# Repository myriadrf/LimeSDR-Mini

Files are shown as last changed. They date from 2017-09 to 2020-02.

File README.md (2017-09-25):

# LimeSDR-Mini

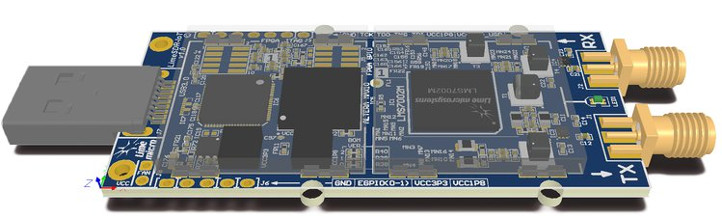
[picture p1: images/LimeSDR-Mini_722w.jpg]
LimeSDR-Mini board


The [LimeSDR-Mini](https://myriadrf.org/projects/limesdr/) board provides a hardware platform for developing and prototyping high-performance and logic-intensive digital and RF designs using Altera’s MAX10 FPGA and Lime Microsystems transceiver.

* **FPGA Features**
  * 169-pin FBGA package
  * 16 K Les
  * 549 KB M9K memory
  * 2,368 KB user flash memory
  * 4 x fractional phase locked loops (PLLs)
  * 45 x 18x18-bit multipliers
  * 130 x general purpose input/output (GPIO)
  * Single supply voltage
  * Flash feature
  * FPGA configuration via JTAG
* **EEPROM memory:** 2 x 128 KB for RF transciever MCU firmware and data
* **Flash memory:** 1 x 4 MB flash memory for data
* **General user inputs/outputs:**
  * 2 x dual color (red + green) LED
  * 8 x FPGA GPIO pinheader (3.3 V)
* **Connectivity:**
  * USB 3.0 Type-A (FTDI FT601 controller)
  * 2 x coaxial RF (SMA) connectors (each can be switched between high and low frequency bands)
  * U.FL connector for external clock source
  * FPGA GPIO headers
  * FPGA JTAG connector
* **Clock system:**
  * 30.72 MHz onboard VCTCXO
  * Possibility to tune VCTCXO with onboard DAC
  * External clock input via U.FL connector
* **Board dimensions:** 69 mm x 31.4 mm

## Contents

The directory structure is as follows:

      hardware/<version>/
          Libraries/             - Component Libraries
          OutputJobs/            - Output jobs
          PCB/                   - PCB design
          Project Outputs/       - BOM, rule check reports, Gerbers, pick & place files, PDFs
          Schematics/            - Schematic diagrams

## Licensing

The hardware designs are licensed under a Creative Commons Attribution 3.0 Unported licence.

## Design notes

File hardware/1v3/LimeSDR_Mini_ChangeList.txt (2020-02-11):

Changes:

LimeSDR_Mini_1v2_DB_DFMr2:
 - R44 made NF (BOM version)
 - LimeSDR_Mini_1v2_schematic_r2.PDF generated
 - LimeSDR_Mini_1v2_BOMr2.xls updated
 
LimeSDR_Mini_1v3:
 - Initial version from LimeSDR_Mini_1v2_DB_DFMr2
 - 1.8V and 3.3V rail LDOs changed
 - Capacitors C194 and C195 added for LMS power
 - HW version changed (affects only PCB physical pin connection)
 - BOM version changed (R44 is now fit)
 - Layout improvements (FT connection)

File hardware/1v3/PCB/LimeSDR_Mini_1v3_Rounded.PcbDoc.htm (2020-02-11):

Reporting Options

# File in Previous Format

Date | : | 2019-05-28
Time | : | 12:08:12
Filename | : | D:\Lime\LimePCBs\LimeSDR_Mini_1v3\Altium Designer design files\PCB\LimeSDR_Mini_1v3_Rounded.PcbDoc

Version | Warning

This file was generated by an earlier version of the software

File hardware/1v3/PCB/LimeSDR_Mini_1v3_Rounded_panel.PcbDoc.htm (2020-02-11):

Reporting Options

# File in Previous Format

Date | : | 2019-05-28
Time | : | 12:52:55
Filename | : | D:\Lime\LimePCBs\LimeSDR_Mini_1v3\Altium Designer design files\PCB\LimeSDR_Mini_1v3_Rounded_panel.PcbDoc

Version | Warning

This file was generated by an earlier version of the software

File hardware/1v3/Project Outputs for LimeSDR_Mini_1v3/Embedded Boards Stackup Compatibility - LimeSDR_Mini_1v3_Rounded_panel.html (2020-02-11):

Altium customize

# Stackup Compatibility

Date: | | 2019-06-04
Time: | | 17:38:27
Elapsed Time: | | 00:00:00
Filename: | | d:\Lime\LimePCBs\LimeSDR_Mini_1v3\Altium Designer design files\PCB\LimeSDR_Mini_1v3_Rounded_panel.PcbDoc

## Layer Stack Compatibility Table

LimeSDR_Mini_1v3_Rounded_panel | LimeSDR_Mini_1v3_Rounded
Top (Signal) | Top (Signal)
L2 (Signal) | L2 (Signal)
L3 (Signal) | L3 (Signal)
L4 (Signal) | L4 (Signal)
L5 (Signal) | L5 (Signal)
L6 (Signal) | L6 (Signal)
L7 (Signal) | L7 (Signal)
Bottom (Signal) | Bottom (Signal)
Open Layer Stack Manager | Open Layer Stack Manager

Back to top

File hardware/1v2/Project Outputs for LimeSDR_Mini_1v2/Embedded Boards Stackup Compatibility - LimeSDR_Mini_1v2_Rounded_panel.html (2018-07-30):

Altium customize

# Stackup Compatibility

Date: | | 2018-04-09
Time: | | 12:49:33
Elapsed Time: | | 00:00:00
Filename: | | E:\Lime Micro\Lime PCBs\LimeSDR_Mini_1v2\Altium Designer design files\PCB\LimeSDR_Mini_1v2_Rounded_panel.PcbDoc

## Layer Stack Compatibility Table

LimeSDR_Mini_1v2_Rounded_panel | LimeSDR_Mini_1v2_Rounded
Top (Signal) | Top (Signal)
L2 (Signal) | L2 (Signal)
L3 (Signal) | L3 (Signal)
L4 (Signal) | L4 (Signal)
L5 (Signal) | L5 (Signal)
L6 (Signal) | L6 (Signal)
L7 (Signal) | L7 (Signal)
Bottom (Signal) | Bottom (Signal)
Open Layer Stack Manager | Open Layer Stack Manager

Back to top

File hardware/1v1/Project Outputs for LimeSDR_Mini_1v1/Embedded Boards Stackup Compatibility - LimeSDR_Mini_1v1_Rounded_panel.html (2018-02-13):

Altium customize

# Stackup Compatibility

Date: | | 2017-11-28
Time: | | 12:33:18
Elapsed Time: | | 00:00:00
Filename: | | E:\Lime Micro\Lime PCBs\LimeSDR_Mini_1v1\Altium Designer design files\PCB\LimeSDR_Mini_1v1_Rounded_panel.PcbDoc

## Layer Stack Compatibility Table

LimeSDR_Mini_1v1_Rounded_panel | LimeSDR_Mini_1v1_Rounded
Top (Signal) | Top (Signal)
L2 (Signal) | L2 (Signal)
L3 (Signal) | L3 (Signal)
L4 (Signal) | L4 (Signal)
L5 (Signal) | L5 (Signal)
L6 (Signal) | L6 (Signal)
L7 (Signal) | L7 (Signal)
Bottom (Signal) | Bottom (Signal)
Open Layer Stack Manager | Open Layer Stack Manager

Back to top

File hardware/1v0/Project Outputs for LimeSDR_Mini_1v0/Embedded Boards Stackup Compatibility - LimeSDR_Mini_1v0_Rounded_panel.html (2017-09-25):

Altium customize

# Stackup Compatibility

Date: | | 2017-09-22
Time: | | 12:15:54
Elapsed Time: | | 00:00:00
Filename: | | D:\Aleksandr\Desktop\LimeSDR_Mini_1v0_Rounded_DFMr1\PCB\LimeSDR_Mini_1v0_Rounded_panel.PcbDoc

## Layer Stack Compatibility Table

LimeSDR_Mini_1v0_Rounded_panel | LimeSDR_Mini_1v0_Rounded
Top (Signal) | Top (Signal)
L2 (Signal) | L2 (Signal)
L3 (Signal) | L3 (Signal)
L4 (Signal) | L4 (Signal)
L5 (Signal) | L5 (Signal)
L6 (Signal) | L6 (Signal)
L7 (Signal) | L7 (Signal)
Bottom (Signal) | Bottom (Signal)
Open Layer Stack Manager | Open Layer Stack Manager

Back to top

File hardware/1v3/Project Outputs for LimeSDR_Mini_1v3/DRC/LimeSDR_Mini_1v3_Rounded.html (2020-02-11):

Altium

# Design Rule Verification Report

Date: | | 2019-06-04
Time: | | 17:38:40
Elapsed Time: | | 00:00:40
Filename: | | d:\Lime\LimePCBs\LimeSDR_Mini_1v3\Altium Designer design files\PCB\LimeSDR_Mini_1v3_Rounded.PcbDoc

Warnings: | | 0
Rule Violations: | | 0

## Summary

Warnings | Count
Total | 0

Rule Violations | Count
Clearance Constraint (Gap=0.1mm) (All),(All) | 0
Short-Circuit Constraint (Allowed=No) (All),(All) | 0
Un-Routed Net Constraint ( (All) ) | 0
Modified Polygon (Allow modified: No), (Allow shelved: No) | 0
Width Constraint (Min=0.1mm) (Max=5mm) (Preferred=0.2mm) (All) | 0
Width Constraint (Min=0.1mm) (Max=7mm) (Preferred=0.2mm) (All) | 0
Routing Layers(All) | 0
Routing Via (MinHoleWidth=0.2mm) (MaxHoleWidth=4.5mm) (PreferredHoleWidth=0.2mm) (MinWidth=0.31mm) (MaxWidth=5mm) (PreferedWidth=0.4mm) (All) | 0
Differential Pairs Uncoupled Length using the Gap Constraints (Min=0.1mm) (Max=0.2mm) (Prefered=0.1mm) and Width Constraints (Min=0.1mm) (Max=0.4mm) (Prefered=0.1mm) (InNet('FX3_XTAL_N') or InNet('FX3_XTAL_P')) | 0
Differential Pairs Uncoupled Length using the Gap Constraints (Min=0.1mm) (Max=0.3mm) (Prefered=0.14mm) and Width Constraints (Min=0.2mm) (Max=0.2mm) (Prefered=0.2mm) (InNetClass('FX3_DATA')) | 0
Differential Pairs Uncoupled Length using the Gap Constraints (Min=0.14mm) (Max=0.14mm) (Prefered=0.14mm) and Width Constraints (Min=0.1mm) (Max=0.2mm) (Prefered=0.2mm) (InNetClass('TX_RF')) | 0
Differential Pairs Uncoupled Length using the Gap Constraints (Min=0.1mm) (Max=0.3mm) (Prefered=0.1mm) and Width Constraints (Min=0.1mm) (Max=0.5mm) (Prefered=0.2mm) (All) | 0
Differential Pairs Uncoupled Length using the Gap Constraints (Min=0.1mm) (Max=0.3mm) (Prefered=0.14mm) and Width Constraints (Min=0.1mm) (Max=0.3mm) (Prefered=0.2mm) (InNetClass('RX_RF')) | 0
Power Plane Connect Rule(Relief Connect )(Expansion=0.508mm) (Conductor Width=0.254mm) (Air Gap=0.254mm) (Entries=4) (All) | 0
Hole Size Constraint (Min=0.2mm) (Max=10mm) (All) | 0
Pads and Vias to follow the Drill pairs settings | 0
Hole To Hole Clearance (Gap=0.15mm) (All),(All) | 0
Minimum Solder Mask Sliver (Gap=0.05mm) (All),(All) | 0
Net Antennae (Tolerance=0mm) (All) | 0
Matched Lengths(Tolerance=5mm) (InNetClass('FT_FIFO')) | 0
Matched Lengths(Tolerance=7mm) (InNetClass('LMS_PORT1')) | 0
Matched Lengths(Tolerance=7.5mm) (InNetClass('LMS_PORT2')) | 0
Component Clearance Constraint ( Horizontal Gap = -1mm, Vertical Gap = Infinite ) (InComponent('IC11') or InComponent('IC11A')),(InComponent('IC11') or InComponent('IC11A')) | 0
Component Clearance Constraint ( Horizontal Gap = 0.01mm, Vertical Gap = 0.254mm ) (All),(All) | 0
Component Clearance Constraint ( Horizontal Gap = -1mm, Vertical Gap = Infinite ) (InComponent('R59') or InComponent('R62')),(InComponent('R59') or InComponent('R62')) | 0
Component Clearance Constraint ( Horizontal Gap = -1mm, Vertical Gap = Infinite ) (InComponent('R28') or InComponent('C22') or InComponent('R29') or InComponent('C20')),(InComponent('R28') or InComponent('C22') or InComponent('R29') or InComponent('C20')) | 0
Component Clearance Constraint ( Horizontal Gap = -1mm, Vertical Gap = Infinite ) (InComponent('MECH5') or InComponent('MECH7') or InComponent('MECH15')),(All) | 0
Height Constraint (Min=0mm) (Max=25.4mm) (Prefered=12.7mm) (All) | 0
Total | 0

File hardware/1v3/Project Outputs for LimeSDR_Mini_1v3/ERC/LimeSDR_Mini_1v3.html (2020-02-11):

Altium

# Electrical Rule Check Report

Date: | | 2019-06-04
Time: | | 17:39:24
Filename: | | d:\Lime\LimePCBs\LimeSDR_Mini_1v3\Altium Designer design files\Project Outputs for LimeSDR_Mini_1v3\ERC\LimeSDR_Mini_1v3.html

Class | Document | Message
Warning | 09_Misc.SchDoc | GND contains IO Pin and Power Pin objects (Pin IC10-4,Pin IC2-4,Pin IC9-5,Pin IC5-F4,Pin IC5-G4,Pin IC10-PAD,Pin IC2-PAD)
Warning | 09_Misc.SchDoc | Net DLY_VCC1P8 has no driving source (Pin C193-2,Pin IC12-1,Pin R84-1,Pin R94-2)
Warning | 09_Misc.SchDoc | Net NetC151_2 has no driving source (Pin C151-2,Pin XO1-7)
Warning | 06_LMS7002M_Power.SchDoc | Net NetC173_2 has no driving source (Pin C173-2,Pin FR34-2,Pin IC15-1,Pin IC15-6)
Warning | 06_LMS7002M_Power.SchDoc | Net NetC187_2 has no driving source (Pin C187-2,Pin FR35-2,Pin IC16-1,Pin IC16-6)
Warning | 09_Misc.SchDoc | Net NetC191_1 has no driving source (Pin C191-1,Pin IC12-2,Pin R76-1,Pin R82-2)
Warning | 09_Misc.SchDoc | Net NetC192_1 has no driving source (Pin C192-1,Pin IC13-2,Pin R78-1,Pin R83-2)
Warning | 07_FPGA.SchDoc | Net NetIC5_E7 has no driving source (Pin IC5-E7,Pin R47-2)
Warning | 09_Misc.SchDoc | Net NetIC14_5 has no driving source (Pin IC14-5,Pin R80-1,Pin R81-1)
Warning | 06_LMS7002M_Power.SchDoc | Net NetIC15_5 has no driving source (Pin IC15-5,Pin R86-1,Pin R87-2)
Warning | 06_LMS7002M_Power.SchDoc | Net NetIC16_5 has no driving source (Pin IC16-5,Pin R88-1,Pin R89-2)
Warning | 09_Misc.SchDoc | Net TCXO_VC has no driving source (Pin C161-2,Pin R67-1,Pin R68-1,Pin XO1-1)
Warning | 08_USB3_0_device.SchDoc | Net USB_SSRX_N has no driving source (Pin ESD3-7,Pin IC6-34,Pin J7-8)
Warning | 08_USB3_0_device.SchDoc | Net USB_SSRX_P has no driving source (Pin ESD3-8,Pin IC6-35,Pin J7-9)
Warning | 09_Misc.SchDoc | Net VCC5P0_USB has no driving source (Pin C176-2,Pin C181-2,Pin FR12-2,Pin IC12-7,Pin IC13-1,Pin IC13-7,Pin J3-7,Pin R15-1,Pin R21-1,Pin R41-1,Pin R69-1,Pin R94-1)

Back to top

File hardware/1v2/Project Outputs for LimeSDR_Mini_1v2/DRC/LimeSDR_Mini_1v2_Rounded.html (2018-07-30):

Altium

# Design Rule Verification Report

Date: | | 2018-04-09
Time: | | 12:51:00
Elapsed Time: | | 00:00:55
Filename: | | E:\Saniok\Lime Micro\Lime PCBs\LimeSDR_Mini_1v2\Altium Designer design files\PCB\LimeSDR_Mini_1v2_Rounded.PcbDoc

Warnings: | | 0
Rule Violations: | | 0

## Summary

Warnings | Count
Total | 0

Rule Violations | Count
Component Clearance Constraint ( Horizontal Gap = -1mm, Vertical Gap = Infinite ) (InComponent('IC11') or InComponent('IC11A')),(InComponent('IC11') or InComponent('IC11A')) | 0
Component Clearance Constraint ( Horizontal Gap = -1mm, Vertical Gap = Infinite ) (InComponent('R59') or InComponent('R62')),(InComponent('R59') or InComponent('R62')) | 0
Component Clearance Constraint ( Horizontal Gap = -1mm, Vertical Gap = Infinite ) (InComponent('MECH5') or InComponent('MECH7') or InComponent('MECH15')),(All) | 0
Component Clearance Constraint ( Horizontal Gap = -1mm, Vertical Gap = Infinite ) (InComponent('R28') or InComponent('C22') or InComponent('R29') or InComponent('C20')),(InComponent('R28') or InComponent('C22') or InComponent('R29') or InComponent('C20')) | 0
Differential Pairs Uncoupled Length using the Gap Constraints (Min=0.1mm) (Max=0.2mm) (Prefered=0.1mm) and Width Constraints (Min=0.1mm) (Max=0.4mm) (Prefered=0.1mm) (InNet('FX3_XTAL_N') or InNet('FX3_XTAL_P')) | 0
Matched Lengths(Tolerance=5mm) (InNetClass('FT_FIFO')) | 0
Net Antennae (Tolerance=0mm) (All) | 0
Minimum Solder Mask Sliver (Gap=0.05mm) (All),(All) | 0
Hole To Hole Clearance (Gap=0.15mm) (All),(All) | 0
Routing Layers(All) | 0
Clearance Constraint (Gap=0.1mm) (All),(All) | 0
Short-Circuit Constraint (Allowed=No) (All),(All) | 0
Un-Routed Net Constraint ( (All) ) | 0
Width Constraint (Min=0.1mm) (Max=5mm) (Preferred=0.2mm) (All) | 0
Routing Via (MinHoleWidth=0.2mm) (MaxHoleWidth=4.5mm) (PreferredHoleWidth=0.2mm) (MinWidth=0.31mm) (MaxWidth=5mm) (PreferedWidth=0.4mm) (All) | 0
Pads and Vias to follow the Drill pairs settings | 0
Hole Size Constraint (Min=0.2mm) (Max=10mm) (All) | 0
Differential Pairs Uncoupled Length using the Gap Constraints (Min=0.1mm) (Max=0.3mm) (Prefered=0.1mm) and Width Constraints (Min=0.1mm) (Max=0.5mm) (Prefered=0.2mm) (All) | 0
Component Clearance Constraint ( Horizontal Gap = 0.01mm, Vertical Gap = 0.254mm ) (All),(All) | 0
Modified Polygon (Allow modified: No), (Allow shelved: No) | 0
Matched Lengths(Tolerance=7mm) (InNetClass('LMS_PORT1')) | 0
Matched Lengths(Tolerance=7.5mm) (InNetClass('LMS_PORT2')) | 0
Differential Pairs Uncoupled Length using the Gap Constraints (Min=0.1mm) (Max=0.3mm) (Prefered=0.14mm) and Width Constraints (Min=0.2mm) (Max=0.2mm) (Prefered=0.2mm) (InNetClass('FX3_DATA')) | 0
Differential Pairs Uncoupled Length using the Gap Constraints (Min=0.14mm) (Max=0.14mm) (Prefered=0.14mm) and Width Constraints (Min=0.1mm) (Max=0.2mm) (Prefered=0.2mm) (InNetClass('TX_RF')) | 0
Differential Pairs Uncoupled Length using the Gap Constraints (Min=0.1mm) (Max=0.3mm) (Prefered=0.14mm) and Width Constraints (Min=0.1mm) (Max=0.3mm) (Prefered=0.2mm) (InNetClass('RX_RF')) | 0
Width Constraint (Min=0.1mm) (Max=7mm) (Preferred=0.2mm) (All) | 0
Power Plane Connect Rule(Relief Connect )(Expansion=0.508mm) (Conductor Width=0.254mm) (Air Gap=0.254mm) (Entries=4) (All) | 0
Height Constraint (Min=0mm) (Max=25.4mm) (Prefered=12.7mm) (All) | 0
Total | 0

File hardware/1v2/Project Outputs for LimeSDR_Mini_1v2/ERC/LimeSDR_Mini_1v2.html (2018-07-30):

Altium

# Electrical Rule Check Report

Date: | | 2018-04-09
Time: | | 12:51:56
Filename: | | E:\Saniok\Lime Micro\Lime PCBs\LimeSDR_Mini_1v2\Altium Designer design files\Project Outputs for LimeSDR_Mini_1v2\ERC\LimeSDR_Mini_1v2.html

Class | Document | Message
Warning | 09_Misc.SchDoc | GND contains IO Pin and Power Pin objects (Pin IC10-4,Pin IC2-4,Pin IC9-5,Pin IC5-E3,Pin IC5-E4,Pin IC5-F4,Pin IC5-G4,Pin IC10-PAD,Pin IC2-PAD)
Warning | 09_Misc.SchDoc | Net NetC151_2 has no driving source (Pin C151-2,Pin XO1-7)
Warning | 06_LMS7002M_Power.SchDoc | Net NetC173_2 has no driving source (Pin C173-2,Pin FR34-2,Pin IC15-1,Pin IC15-6)
Warning | 06_LMS7002M_Power.SchDoc | Net NetC187_2 has no driving source (Pin C187-2,Pin FR35-2,Pin IC16-1,Pin IC16-6)
Warning | 07_FPGA.SchDoc | Net NetIC5_E7 has no driving source (Pin IC5-E7,Pin R47-2)
Warning | 09_Misc.SchDoc | Net NetIC14_5 has no driving source (Pin IC14-5,Pin R80-1,Pin R81-1)
Warning | 06_LMS7002M_Power.SchDoc | Net NetIC15_5 has no driving source (Pin IC15-5,Pin R86-1,Pin R87-2)
Warning | 06_LMS7002M_Power.SchDoc | Net NetIC16_5 has no driving source (Pin IC16-5,Pin R88-1,Pin R89-2)
Warning | 09_Misc.SchDoc | Net TCXO_VC has no driving source (Pin C161-2,Pin R67-1,Pin R68-1,Pin XO1-1)
Warning | 08_USB3_0_device.SchDoc | Net USB_SSRX_N has no driving source (Pin ESD3-7,Pin IC6-34,Pin J7-8)
Warning | 08_USB3_0_device.SchDoc | Net USB_SSRX_P has no driving source (Pin ESD3-8,Pin IC6-35,Pin J7-9)

Back to top

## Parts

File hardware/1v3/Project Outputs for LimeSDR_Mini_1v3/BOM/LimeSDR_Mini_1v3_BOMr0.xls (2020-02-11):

Item # | Comment | Quantity | Designator | Footprint | Manufacturer | Manufacturer Part Number 1 | Supplier 1 | Supplier Part Number 1 | Part Description | Assembly Info
1 | 10pF, 25V | 1 | C1 | CAP0402 | AVX | 04023A100JAT2A | Farnell | 2332478RL | 10pF ±5% 25V C0G, NP0 Ceramic Capacitor -55°C ~ 125°C Surface Mount, MLCC 0402 (1005 Metric) 0.039" L x 0.020" W (1.00mm x 0.50mm)
2 | 1uF, 10V | 6 | C2, C153, C157, C164, C168, C193 | CAP0402 | TDK | C1005X5R1E105K050BC | Digi-Key | 445-9066-1-ND | 1µF ±10% 10V X5R Ceramic Capacitor -55°C ~ 85°C Surface Mount, MLCC 0402 (1005 Metric) 0.039" L x 0.020" W (1.00mm x 0.50mm)
3 | 100pF, 50V | 18 | C3, C5, C7, C8, C12, C19, C20, C22, C23, C159, C160, C166, C167, C170, C171, C183, C186, C189 | CAP0402 | Yageo | CC0402JRNPO9BN101 | Digi-Key | 311-1024-1-ND | 100pF ±5% 50V C0G, NP0 Ceramic Capacitor -55°C ~ 125°C Surface Mount, MLCC 0402 (1005 Metric) 0.039" L x 0.020" W (1.00mm x 0.50mm) | NF(C12 C19 C20 C22 C183 C186 C189)
4 | 100nF, 16V | 26 | C4, C6, C9, C10, C11, C21, C87, C123, C125, C127, C147, C148, C149, C150, C155, C156, C158, C161, C162, C163, C165, C169, C172, C174, MN11, MN14 | CAP0402 | Murata Electronics | GRM155R71C104KA88D | Mouser | 81-GRM155R71C104KA88 | 0.10µF ±10% 16V X7R Ceramic Capacitor -55°C ~ 125°C Surface Mount, MLCC 0402 (1005 Metric) 0.039" L x 0.020" W (1.00mm x 0.50mm) | NF(C11 C21 C150)
5 | 47pF, 50V | 4 | C13, C16, C24, C27 | CAP0402 | TDK Corporation | GRM1555C1H470FA01D | Digi-Key | 490-6241-1-ND | 47pF ±1% 50V C0G, NP0 Ceramic Capacitor -55°C ~ 125°C Surface Mount, MLCC 0402 (1005 Metric) 0.039" L x 0.020" W (1.00mm x 0.50mm)
6 | 510pF | 6 | C14, C15, C25, C26, MN19, MN22 | CAP0402 | Murata Electronics North America | GRM1555C1H511JA01D | Digi-Key | 490-3237-1-ND | 510pF ±5% 50V C0G, NP0 Ceramic Capacitor -55°C ~ 125°C Surface Mount, MLCC 0402 (1005 Metric) 0.039" L x 0.020" W (1.00mm x 0.50mm)
7 | 1uF, 6.3V | 60 | C30, C32, C34, C36, C38, C40, C41, C42, C43, C44, C45, C46, C47, C48, C49, C50, C51, C52, C53, C55, C56, C57, C58, C59, C60, C62, C64, C66, C67, C68, C69, C70, C71, C72, C73, C74, C75, C76, C77, C78, C79, C80, C81, C82, C83, C84, C85, C86, C89, C96, C103, C109, C113, C129, C131, C133, C135, C138, C146, C190 | CAP0201 | TDK Corporation | JMK063ABJ105MP-F | Digi-Key | 587-5864-2-ND | 1µF ±20% 6.3V X5R Ceramic Capacitor -55°C ~ 85°C Surface Mount, MLCC 0201 (0603 Metric) 0.024" L x 0.012" W (0.60mm x 0.30mm)
8 | 1nF, 10% | 11 | C31, C33, C35, C37, C39, C54, C61, C63, C65, C194, C195 | CAP0201 | TDK Corporation | C0603X7R1E102K030BA | Digi-Key | 445-7275-1-ND | 1000pF ±10% 25V X7R Ceramic Capacitor -55°C ~ 125°C Surface Mount, MLCC 0201 (0603 Metric) 0.024" L x 0.012" W (0.60mm x 0.30mm)
9 | 10uF, 6.3V | 11 | C88, C95, C102, C108, C112, C128, C137, C145, C175, C180, C184 | CAP0603 | Yageo | CC0603MRX5R5BB106 | Digi-Key | 311-1448-2-ND | 10µF ±20% 6.3V X5R Ceramic Capacitor -55°C ~ 85°C Surface Mount, MLCC 0603 (1608 Metric) 0.063" L x 0.031" W (1.60mm x 0.80mm)
10 | 100nF, 6.3V | 32 | C90, C91, C92, C93, C94, C97, C98, C99, C100, C101, C104, C105, C106, C107, C110, C111, C114, C115, C116, C117, C118, C119, C120, C121, C122, C130, C132, C134, C136, C139, C141, C143 | CAP0201 | Murata | GRT033C81A104KE01D | Digi-Key | 490-12232-1-ND | 0.10µF ±10% 6.3V X6S Ceramic Capacitor -55°C ~ 105°C Surface Mount, MLCC 0201 (0603 Metric) 0.024" L x 0.012" W (0.60mm x 0.30mm)
11 | 10pF, 5% | 2 | C124, C126 | CAP0402 | AVX | 04023A100JAT2A | Farnell | 2332478RL | 10pF ±5% 25V C0G, NP0 Ceramic Capacitor -55°C ~ 125°C Surface Mount, MLCC 0402 (1005 Metric) 0.039" L x 0.020" W (1.00mm x 0.50mm)
12 | 10nF, 50V | 7 | C17, C18, C28, C29, C140, C142, C144 | CAP0402 | Murata Electronics North America | GRM155R71H103KA88D | Digi-Key | 490-4516-2-ND | 10000pF ±10% 50V Ceramic Capacitor X7R 0402 (1005 Metric)
13 | 18nF, 16V | 1 | C151 | CAP0402 | Yageo | CC0402KRX7R7BB183 | Digi-Key | 311-1706-1-ND | CAP CER 0.018UF 16V X7R 0402
14 | 47pF | 2 | C152, C154 | CAP0402 | TDK Corporation | GRM1555C1H470FA01D | Digi-Key | 490-6241-1-ND | 47pF ±1% 50V C0G, NP0 Ceramic Capacitor -55°C ~ 125°C Surface Mount, MLCC 0402 (1005 Metric) 0.039" L x 0.020" W (1.00mm x 0.50mm) | NF(C152 C154)
15 | 4.7uF, 6.3V | 6 | C173, C178, C179, C185, C187, C188 | CAP0402 | Murata Electronics North America | GRM155R60J475ME87D | Digi-Key | 490-5408-1-ND | 4.7µF ±20% 6.3V X5R Ceramic Capacitor -55°C ~ 85°C Surface Mount, MLCC 0402 (1005 Metric) 0.039" L x 0.020" W (1.00mm x 0.50mm)
16 | 22uF, 10V | 4 | C176, C177, C181, C182 | CAP0603 | TDK Corporation | C1608X5R1A226M080AC | Mouser | 810-C1608X5R1A226M | 22µF ±20% 10V X5R Ceramic Capacitor -55°C ~ 85°C Surface Mount, MLCC 0603 (1608 Metric) 0.063" L x 0.031" W (1.60mm x 0.80mm)
17 | 470pF, 50V | 2 | C191, C192 | CAP0402 | TDK Corporation | C1005C0G1H471J050BA | Digi-Key | 445-2656-6-ND | 470pF ±5% 50V Ceramic Capacitor C0G, NP0 0402 (1005 Metric)
18 | ESD8472 | 2 | ESD1, ESD2 | ESD8472_X3DFN2 | ON Semiconductor | ESD8472MUT5G | Digi-Key | ESD8472MUT5GOSCT-ND | TVS DIODE 5.3VWM 14VC X3DFN2 | NF(ESD1 ESD2)
19 | ESD7016 | 1 | ESD3 | ESD7016 | ON Semiconductor | ESD7016MUTAG | Digi-Key | ESD7016MUTAGOSDKR-ND | TVS DIODE 5VWM 10VC 8UDFN
20 | 5V DC FAN | 1 | FAN1 |  | Sunon Fans | MC30060V2-000U-A99 | Digi-Key | 259-1572-ND | FAN AXIAL 30X6.9MM 5VDC WIRE | NF(FAN1)
21 | Fiducial | 1 | FL1 | Fiducial_local
22 | 600R, 0.27A | 36 | FR1, FR2, FR3, FR4, FR5, FR6, FR7, FR8, FR9, FR10, FR15, FR16, FR17, FR18, FR19, FR23, FR24, FR25, FR26, FR27, FR28, FR29, FR30, FR31, FR32, FR33, FR36, FR37, FR38, FR39, FR40, FR41, FR42, FR43, FR44, FR45 | RES0201 | Taiyo Yuden | BK0603TS601-T | Digi-Key | 587-3277-1-ND | FERRITE BEAD 600 OHM 0201 1LN
23 | 220R, 0.9A | 7 | FR11, FR13, FR14, FR21, FR22, FR34, FR35 | RES0402 | TDK Corporation | MPZ1005S221ET000 | Digi-Key | 445-9329-2-ND | FERRITE BEAD 220 OHM 0402 1LN
24 | 600R, 2A | 2 | FR12, FR20 | RES0805 | TDK Corporation | MPZ2012S601AT000 | Digi-Key | 445-2206-2-ND | FERRITE BEAD 600 OHM 0805 1LN
25 | LMS7002M | 1 | IC1 | LMS7002M_v5 | Lime Microsystems | LMS7002M | Lime Microsystems | LMS7002M | IC FPRF Transceiver LMS7002M; 261 pin aQFN
26 | M24128 | 2 | IC2, IC10 | M24128-DFMC6TG | STMicroelectronics | M24128-DFMC6TG | Digi-Key | 497-15739-1-ND | EEPROM Memory IC 128Kb (16K x 8) I²C 1MHz 450ns 8-UFDFPN (2x3)
27 | SKY13411-374LF | 2 | IC3, IC4 | SKY13411-374LF | Skyworks Solutions Inc. | SKY13411-374LF | Digi-Key | 863-1455-1-ND | RF Switch IC 802.11a/b/g/n DPDT 50 Ohm 6-MLPD (1.5x1.5)
28 | 10M16SAU169C8G | 1 | IC5 | 10M16SAU169C8G | Altera | 10M16SAU169C8G | Digi-Key | 544-3110-ND | IC FPGA/CPLD NV 130 I/O 169UBGA
29 | FT601Q | 1 | IC6 | FT601Q | FTDI, Future Technology Devices International Ltd | FT601Q-B-T | Digi-Key | 768-1311-ND | IC USB3-32BIT SYNC FIFO 76QFN
30 | LMK00105 | 1 | IC7 | LMK00105SQ | Texas Instruments | LMK00105SQ/NOPB | Digi-Key | LMK00105SQ/NOPBCT-ND | IC CLK BUFFER 2:5 200MHZ 24WQFN
31 | LM75 | 1 | IC8 | HWSON8_LM75 | NXP Semiconductors | LM75BTP,147 | Digi-Key | 568-9815-2-ND | SENSOR TEMPERATURE I2C 8HWSON | NF(IC8)
32 | DAC5311IDCKR | 1 | IC9 | AD5601_SOT23-6 | Texas Instruments | DAC5311IDCKR | Digi-Key | 296-24180-1-ND | 8 Bit Digital to Analog Converter 1 SC-70-6
33 | W25Q40EWUXIE | 1 | IC11 | W25Q40EWUXIE_8-USON | Winbond Electronics | W25Q40EWUXIE TR | Digi-Key | W25Q40EWUXIE CT-ND | FLASH - NOR Memory IC 4Mb (512K x 8) SPI 8-USON (2x3)
34 | MX25U1635EM1I | 1 | IC11A | MX25U1635EM1I-10G_SOP8_150mil | Macronix | MX25U1635EM1I-10G | Digi-Key | 1092-1123-ND | FLASH - NOR Memory IC 16Mb (2M x 8) SPI 104MHz 8-SOP | NF(IC11A)
35 | LMZ10501 | 2 | IC12, IC13 | LMZ10501 | Texas Instruments | LMZ10501SILR | Digi-Key | 296-37104-1-ND | n Non-Isolated PoL Module DC DC Converter 1 Output 0.6 ~ 3.6 V 1A 2.7V - 5.5V Input
36 | LD39100PUR | 3 | IC14, IC15, IC16 | LD39100PUR | STMicroelectronics | LD39100PUR | Digi-Key | 497-11013-1-ND | Linear Voltage Regulator IC Positive Adjustable Output 0.8 V ~ 4.5 V 1A 6-DFN (3x3)
37 | SMA board edge | 2 | J1, J2 | SMA_connector_board_edge_SM | RF Solutions | CON-SMA-EDGE-S | Digi-Key | CON-SMA-EDGE-S-ND | SMA Connector Jack, Female Socket Board Edge, End Launch Solder
38 | FPGA JTAG (board edge) | 1 | J3 | Header7x1_TH_v2 | Sullins Connector Solutions | PEC07SAAN | Digi-Key | S1012E-07-ND | 7 Positions Header, Unshrouded, Breakaway Connector 0.100" (2.54mm) Through Hole Tin | NF(J3)
39 | FPGA JTAG | 1 | J4 | SWD_10_pin | Harwin Inc | M50-3600542 | Digi-Key | 952-1389-ND | CONN HDR 1.27MM SMD AU 10POS | NF(J4)
40 | FPGA GPIO | 1 | J5 | SWD_10_pin | Harwin Inc | M50-3600542 | Digi-Key | 952-1389-ND | CONN HDR 1.27MM SMD AU 10POS | NF(J5)
41 | FPGA EGPIO (board edge) | 1 | J6 | Header5x1_TH_v2 | Amphenol FCI | 69190-405HLF | Digi-Key | 609-4726-ND | 5 Positions Header Connector 0.100" (2.54mm) Through Hole Tin | NF(J6)
42 | USB3.0_MALE | 1 | J7 | USB3A_SM | Wurth Electronics Inc. | 692112030100 | Digi-Key | 732-3157-ND | USB - A USB 3.0 (USB 3.1 Gen 1, Superspeed) Plug Connector 9 Position Surface Mount, Right Angle
43 | U.FL/MMCX | 2 | J8, J9 | MMCX_UFL_conn_u | Molex, LLC | 0734120110 | Digi-Key | WM5587CT-ND | Ultra Miniature Coaxial Connector Receptacle, Male Pin 50 Ohm Surface Mount Solder
44 | FAN | 1 | J10 | Header2x1_TH_v2 | 3M | 961102-6404-AR | Digi-Key | 3M9447-ND | 2 Positions Header, Unshrouded Connector 0.100" (2.54mm) Through Hole Gold | NF(J10)
45 | LED_RG_SMD | 1 | LED1 | LED-2x0603 | Avago Technologies US Inc. | HSMF-C165 | Digi-Key | 516-1419-1-ND | LED GREEN/RED DIFFUSED 0603 SMD
46 | LED_RG_angle | 1 | LED2 | LED_RG_RIGHT_ANGLE_v2 | Lite-On | LTST-S326KGJRKT | Mouser | 859-LTST-S326KGJRKT | LED GREEN/RED CLEAR 2SMD R/A | NF(LED2)
47 | RFI Shield clip | 12 | MECH1, MECH2, MECH3, MECH4, MECH6, MECH8, MECH9, MECH10, MECH11, MECH12, MECH13, MECH14 | RFI_SHIELD_CLPS_MINI | HARWIN | S0971-46R | Farnell | 2361677 | RFI SHIELD CLIP MINI TIN SMD | NF(MECH6 MECH8 MECH9 MECH10 MECH11 MECH12 MECH13 MECH14)
48 | RFI Shield | 3 | MECH5, MECH7, MECH15 | WurthElectronic_RF_shield | WURTH ELEKTRONIK | 36003250 | Farnell | 1909662 | Enclosure, Shielding Cabinet Cover, Shielding Cabinet, 25 mm, 25 mm, 3 mm, Tin Plate | NF(MECH7 MECH15)
49 | Spacer M3 | 2 | MECH16, MECH17 |  | BOSSARD | TDYSFF-M3/5 | TME | TDYSFF-M3/5 | Screwed spacer sleeve; Int.thread: M3; 5mm; brass | NF(MECH16 MECH17)
50 | Screws M3 | 4 | MECH18, MECH19, MECH20, MECH21 |  | KRAFTBERG | M3X3/D7985, M3X3/D7985, M3X8/D7985B, M3X8/D7985B | TME | M3X3/D7985, M3X3/D7985, M3X8/D7985B, M3X8/D7985B | Screw; M3x3; DIN:7985; Head: cheese head; Phillips; steel; zinc; PH1, Screw; M3x3; DIN:7985; Head: cheese head; Phillips; steel; zinc; PH1, Screw; M3x8; DIN:7985; Head: cheese head; Phillips; black finish, Screw; M3x8; DIN:7985; Head: cheese head; Phillips; black finish | NF(MECH18 MECH19 MECH20 MECH21)
51 | 8.2nH, 5% | 3 | MN1, MN2, MN20 | RES0402 | COILCRAFT | 0402HP-8N2XJLU | Farnell | 2285826 | Surface Mount High Frequency Inductor, 0402HP Series, 8.2 nH, ± 5%, 0402 [1005 Metric], 5.4 GHz | NF(MN20)
52 | 0.8pF | 2 | MN3, MN6 | CAP0402 | Murata Electronics North America | GRM1555C1HR80BA01D | Digi-Key | 490-6269-1-ND | 0.80pF ±0.1pF 50V C0G, NP0 Ceramic Capacitor -55°C ~ 125°C Surface Mount, MLCC 0402 (1005 Metric) 0.039" L x 0.020" W (1.00mm x 0.50mm)
53 | 1pF | 3 | MN4, MN12, MN17 | CAP0402 | TDK Corporation | C1005C0G1H010B050BA | Digi-Key | 445-4854-6-ND | 1pF ±0.1pF 50V C0G, NP0 Ceramic Capacitor -55°C ~ 125°C Surface Mount, MLCC 0402 (1005 Metric) 0.039" L x 0.020" W (1.00mm x 0.50mm) | NF(MN4 MN12)
54 | 0.5pF | 2 | MN5, MN16 | CAP0402 | Yageo | CC0402CRNPO9BNR50 | Digi-Key | 311-1001-1-ND | 0.50pF ±0.25pF 50V C0G, NP0 Ceramic Capacitor -55°C ~ 125°C Surface Mount, MLCC 0402 (1005 Metric) 0.039" L x 0.020" W (1.00mm x 0.50mm) | NF(MN16)
55 | 100uH | 2 | MN7, MN8 | RES0805 | TDK Corporation | MLF2012C101KT000 | Digi-Key | 445-1071-1-ND | FIXED IND 100UH 2MA 3.1 OHM SMD
56 | 0R | 30 | MN9, MN10, R14, R15, R20, R21, R27, R28, R29, R30, R31, R40, R41, R42, R43, R44, R52, R57, R59, R61, R62, R65, R69, R71, R74, R77, R79, R90, R93, R94 | RES0402 | Yageo | RC0402JR-070RL | Digi-Key | 311-0.0JRTR-ND | RES SMD 0.0OHM JUMPER 1/16W 0402 | NF(R14 R15 R20 R21 R41 R62 R71 R74 R77 R93 R94)
57 | 2pF | 3 | MN13, MN15, MN18 | CAP0402 | AVX | 04025U2R0BAT2A | Farnell | 2332536 | SMD Multilayer Ceramic Capacitor, U Series, 2 pF, ± 0.1pF, C0G / NP0, 50 V, 0402 [1005 Metric]
58 | 1.2pF | 1 | MN21 | CAP0402 | Murata Electronics North America | GRM1555C1H1R2CA01D | Digi-Key | 490-5927-1-ND | '1.2pF ±0.25pF 50V C0G, NP0 Ceramic Capacitor -55°C ~ 125°C Surface Mount, MLCC 0402 (1005 Metric) 0.039" L x 0.020" W (1.00mm x 0.50mm)
59 | 100uH | 2 | MN23, MN24 | RES0805_0603 | TDK Corporation | MLF2012C101KT000 | Digi-Key | 445-1071-1-ND | FIXED IND 100UH 2MA 3.1 OHM SMD | NF(MN23 MN24)
60 | 10k, 1% | 25 | R1, R2, R3, R4, R5, R10, R11, R34, R35, R36, R37, R38, R45, R46, R47, R48, R49, R51, R53, R54, R55, R58, R68, R80, R89 | RES0402 | Yageo | RC0402FR-0710KL | Digi-Key | 311-10.0KLRTR-ND | RES SMD 10K OHM 1% 1/16W 0402 | NF(R35)
61 | 49.9R, 1% | 7 | R6, R7, R8, R9, R23, R24, R63 | RES0402 | Samsung Electro-Mechanics America, Inc. | RC1005F49R9CS | Digi-Key | 1276-3469-6-ND | RES SMD 49.9 OHM 1% 1/16W 0402
62 | 2k2, 1% | 2 | R12, R13 | RES0402 | Stackpole Electronics Inc | RMCF0402FT2K20 | Digi-Key | RMCF0402FT2K20CT-ND | RES SMD 2.2K OHM 1% 1/16W 0402
63 | 560R, 1% | 1 | R16 | RES0402 | Vishay Dale | CRCW0402560RFKED | Digi-Key | 541-560LCT-ND | RES SMD 560 OHM 1% 1/16W 0402 | NF(R16)
64 | 100R, 1% | 7 | R17, R22, R25, R70, R72, R73, R75 | RES0402 | Stackpole Electronics Inc. | RMCF0402FT100R | Digi-Key | RMCF0402FT100RDKR-ND | RES SMD 100 OHM 1% 1/16W 0402 | NF(R17 R22 R73 R75)
65 | 2.49k, 1% | 1 | R18 | RES0402 | Yageo | RC0402FR-072K49L | Digi-Key | 311-2.49KLRDKR-ND | RES SMD 2.49K OHM 1% 1/16W 0402
66 | 1k, 1% | 4 | R19, R39, R64, R66 | RES0402 | Stackpole Electronics Inc | RMCF0402FT1K00 | Digi-Key | RMCF0402FT1K00TR-ND | RES SMD 1K OHM 1% 1/16W 0402 | NF(R19)
67 | 0R | 1 | R26 | RES0201 | Rohm Semiconductor | RC0201FR-070RL | Digi-Key | 311-0.0MCT-ND | RES SMD 0.0OHM JUMPER 1/20W 0201
68 | 10R | 4 | R32, R33, R91, R92 | RES0201 | Panasonic Electronic Components | ERJ-1GEF10R0C | Digi-Key | P10.0ABCT-ND | RES SMD 10 OHM 1% 1/20W 0201
69 | 4K7, 1% | 3 | R50, R81, R84 | RES0402 | Yageo | RC0402FR-074K7L | Digi-Key | 311-4.7KLRCT-ND | ±1% 0.063W, 1/16W Chip Resistor 0402 (1005 Metric) Moisture Resistant Thick Film
70 | 1k6, 1% | 1 | R56 | RES0402 | Yageo | RC0402FR-071K6L | Digi-Key | YAG3045CT-ND | RES SMD 1.6K OHM 1% 1/16W 0402
71 | 22R | 4 | R60, R85, R95, R96 | RES0402 | Yageo | RC0402FR-0722RL | Digi-Key | 311-22.0LRTR-ND | RES SMD 22 OHM 1% 1/16W 0402 | NF(R95 R96)
72 | 3k, 1% | 1 | R67 | RES0402 | Vishay Dale | RMCF0402FT3K00 | Digi-Key | RMCF0402FT3K00TR-ND | RES SMD 3K OHM 1% 1/16W 0402
73 | 118k, 1% | 1 | R76 | RES0402 | Yageo | RC0402FR-07118KL | Digi-Key | YAG2369CT-ND | 118 kOhms ±1% 0.063W, 1/16W Chip Resistor 0402 (1005 Metric) Moisture Resistant Thick Film
74 | 187k, 1% | 1 | R78 | RES0402 | Yageo | RC0402FR-07187KL | Digi-Key | 311-187KLRCT-ND | 187 kOhms ±1% 0.063W, 1/16W Chip Resistor 0402 (1005 Metric) Moisture Resistant Thick Film
75 | 150k, 1% | 1 | R82 | RES0402 | Yageo | RC0402JR-07150KL | Digi-Key | 311-150KJRCT-ND | 150 kOhms ±5% 0.063W, 1/16W Chip Resistor 0402 (1005 Metric) Moisture Resistant Thick Film
76 | 82.5k, 1% | 1 | R83 | RES0402 | Yageo | RC0402FR-0782K5L | Digi-Key | 311-82.5KLRCT-ND | 82.5 kOhms ±1% 0.063W, 1/16W Chip Resistor 0402 (1005 Metric) Moisture Resistant Thick Film
77 | 8.2k, 1% | 1 | R86 | RES0402 | Yageo | RC0402FR-078K2L | Digi-Key | 311-8.20KLRCT-ND | RES SMD 8.2K OHM 1% 1/16W 0402
78 | 15k, 1% | 1 | R87 | RES0402 | Yageo | RC0402FR-0715KL | Digi-Key | 311-15.0KLRCT-ND | RES SMD 15K OHM 1% 1/16W 0402
79 | 7.5k, 1% | 1 | R88 | RES0402 | Yageo | RC0402FR-077K5L | Digi-Key | YAG3512CT-ND | ±1% 0.063W, 1/16W Chip Resistor 0402 (1005 Metric) Automotive AEC-Q200, Moisture Resistant Thick Film
80 | TC1-1-13M-45+ | 4 | T1, T2, T3, T4 | TC1-1-13MA+_JA4220-AL_ |  | TC1-1-13M-45+ | Minicircuits | TC1-1-13M-45+ | RF balun; 1:1 ratio; 3 dB bandwidth: 0.3 MHz to 3.5 GHz; 3.8mm x 3.8mm
81 | RF MOSFET | 3 | VT1, VT2, VT3 | BF1105R_SOT143R4 | NXP Semiconductors | BF1105R,215 | Digi-Key | 568-12530-6-ND | RF MOSFET Transistors Trans MOSFET N-CH 7V 0.03A 4pin(3+Tab) | NF(VT1 VT2)
82 | IRLML6244TRPBF | 1 | VT4 | SOT23-3 | Infineon Technologies | IRLML6244TRPBF | Digi-Key | IRLML6244TRPBFTR-ND | N-Channel 20V 6.3A (Ta) 1.3W (Ta) Surface Mount Micro3™/SOT-23
83 | RTX5032A, 40MHz, w VC, w Filter | 1 | XO1 | RAKON_RTX5032A | Rakon | RTX5032A | RAKON | RTX5032A | RTX5032A 40MHz, High performance TCXO, With VC, Filter Enabled, 10-pin 5mm x 3.2 mm x 1.65 mm package
84 | 30MHz | 1 | XT1 | CRYSTAL_4-LCC | AVX Corp/Kyocera Corp | CX3225SB30000D0FPLCC | Digi-Key | 1253-1368-1-ND | 30MHz ±10ppm Crystal 8pF 50 Ohm -40°C ~ 85°C Surface Mount 4-SMD, No Lead (DFN, LCC)
 |  |  |  |  |  |  |  |  |  | Total NF element number: 67
 |  |  |  |  |  |  |  |  |  | All NF elements in one row:
 |  |  |  |  |  |  |  |  |  | NF(C12 C19 C20 C22 C183 C186 C189 C11 C21 C150 C152 C154 ESD1 ESD2 FAN1 IC8 IC11A J3 J4 J5 J6 J10 LED2 MECH6 MECH8 MECH9 MECH10 MECH11 MECH12 MECH13 MECH14 MECH7 MECH15 MECH16 MECH17 MECH18 MECH19 MECH20 MECH21 MN20 MN4 MN12 MN16 R14 R15 R20 R21 R41 R62 R71 R74 R77 R93 R94 MN23 MN24 R35 R16 R17 R22 R73 R75 R19 R95 R96 VT1 VT2)
 |  |  |  |  |  |  |  |  |  | *NOTE: NF(R1 R2) means that elements R1 and R2 are unpopulated (NF)

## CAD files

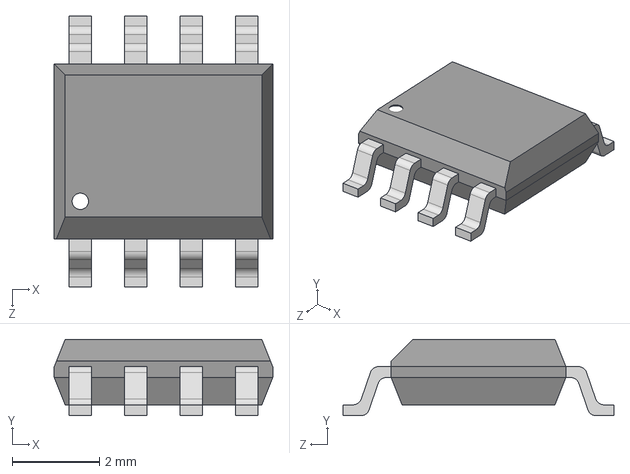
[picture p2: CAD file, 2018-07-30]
hardware/1v2/3D Bodies/User Library-SOIC_N-R8.step
5.00 x 1.75 x 6.20 mm

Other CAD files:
hardware/1v2/3D Bodies/User Library-SOIC_N-R8.SLDPRT

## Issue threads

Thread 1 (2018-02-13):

Step File doesn't show mounting holes

jscatena88, 2018-02-13:
I am attempting to create a 3d printable case for my new Mini. I downloaded the STEP file for the board and noticed it does not have the two mounting holes up near the USB connector nor the 4 side cutouts. Would it be possible to get a new STEP file that has these in it so I can build my case around them?

9600, 2018-02-13:
@ztamosevicius could someone please update the STEP file.

ztamosevicius, 2018-02-13:
Just updated the repo. Check folder "hardware/1v1" for updated data.

Closed 2018-02-13.

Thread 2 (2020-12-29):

LimeSDR-Mini firmware

cederom, 2020-12-29:
Hello world :-)

We are porting LimeSuite to FreeBSD. Working on LimeSDR-Mini. There seems to be a set of issues with LimeSDR both USB and radio part. Where can we find source code repository and support for those issues?

Identified issues so far:
1. LibUSB open / reset impossible on FreeBSD when working as user (only root can reset hardware USB ports).
2. Hardware Self-Test fail with LimeQuickTest.
3. MCU error 3 / Tx Calibration: MCU error 3 (SXR tune failed).
4. MCU error 5 / Tx Calibration: MCU error 5 (Loopback signal weak: not connected/insufficient gain?).

The work in progress is documented here:
https://github.com/myriadrf/LimeSuite/wiki/LimeSDR-on-FreeBSD

9600, 2020-12-29:
Support for LimeSDR hardware is provided by Lime Suite, hence the source code in this repository.

Please run LimeQuickTest on a Linux host, with the latest version of Lime Suite installed, while ensuring that nothing is connected to any of the RF ports and that the board is cold (pass/fail criteria are not valid when a board has been running for some time and is warm). If you still get failures, it could be hardware related. Otherwise I would imagine it to be related to the different host O/S and porting.

cederom, 2020-12-29:
Hello @9600 :-) I am porting the LimeSuite to FreeBSD, some problems seems firmware related (i.e. device reset vs port reset, also the self-test fails). They occur on various other devices and operating systems. Where can we find firmware source code for LimeSDR-Mini? Is it Open-Source?

cederom, 2020-12-29:
Looks like sources are available here:
1. GateWare for FPGA: https://github.com/myriadrf/LimeSDR-Mini_GW
2. MCU Firmware (LMS7002M): https://github.com/myriadrf/LimeSuite/tree/master/mcu_program

Thank you @daniestevez :-)

Closed 2020-12-29.

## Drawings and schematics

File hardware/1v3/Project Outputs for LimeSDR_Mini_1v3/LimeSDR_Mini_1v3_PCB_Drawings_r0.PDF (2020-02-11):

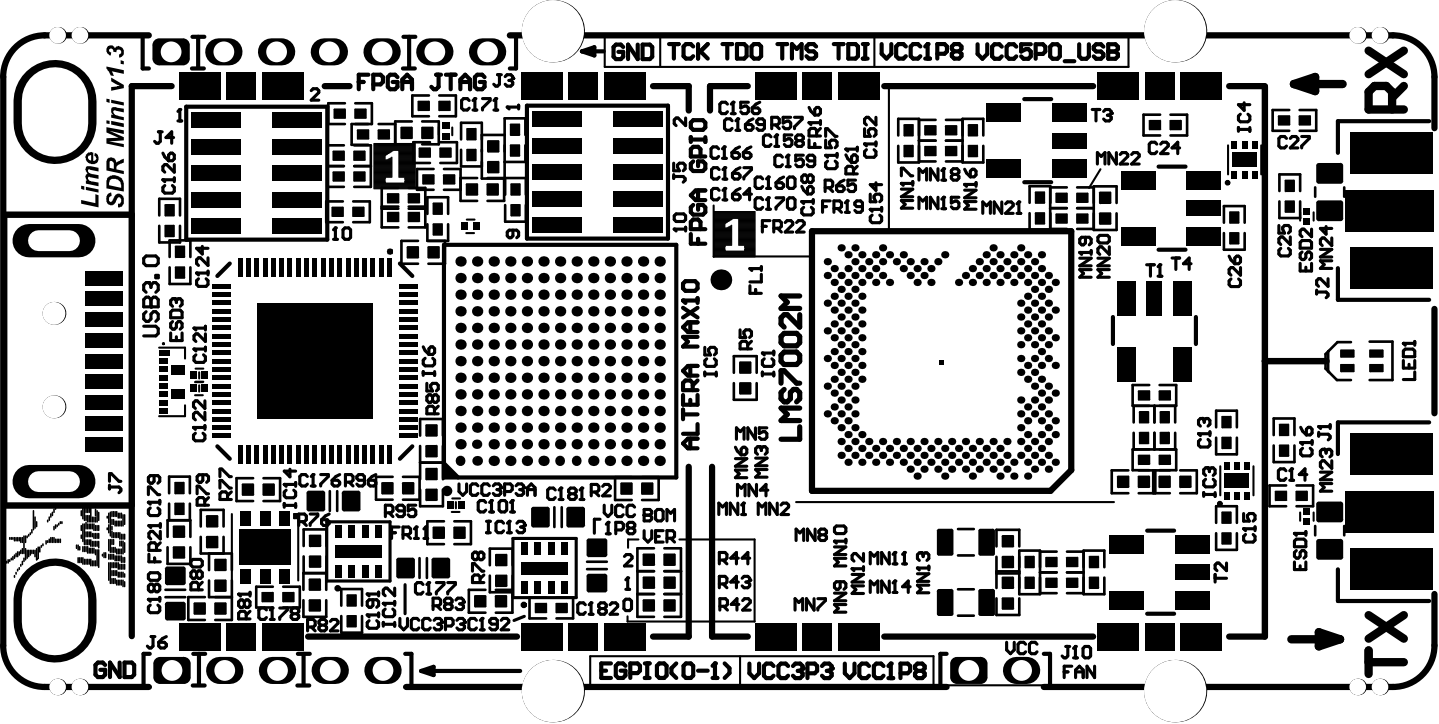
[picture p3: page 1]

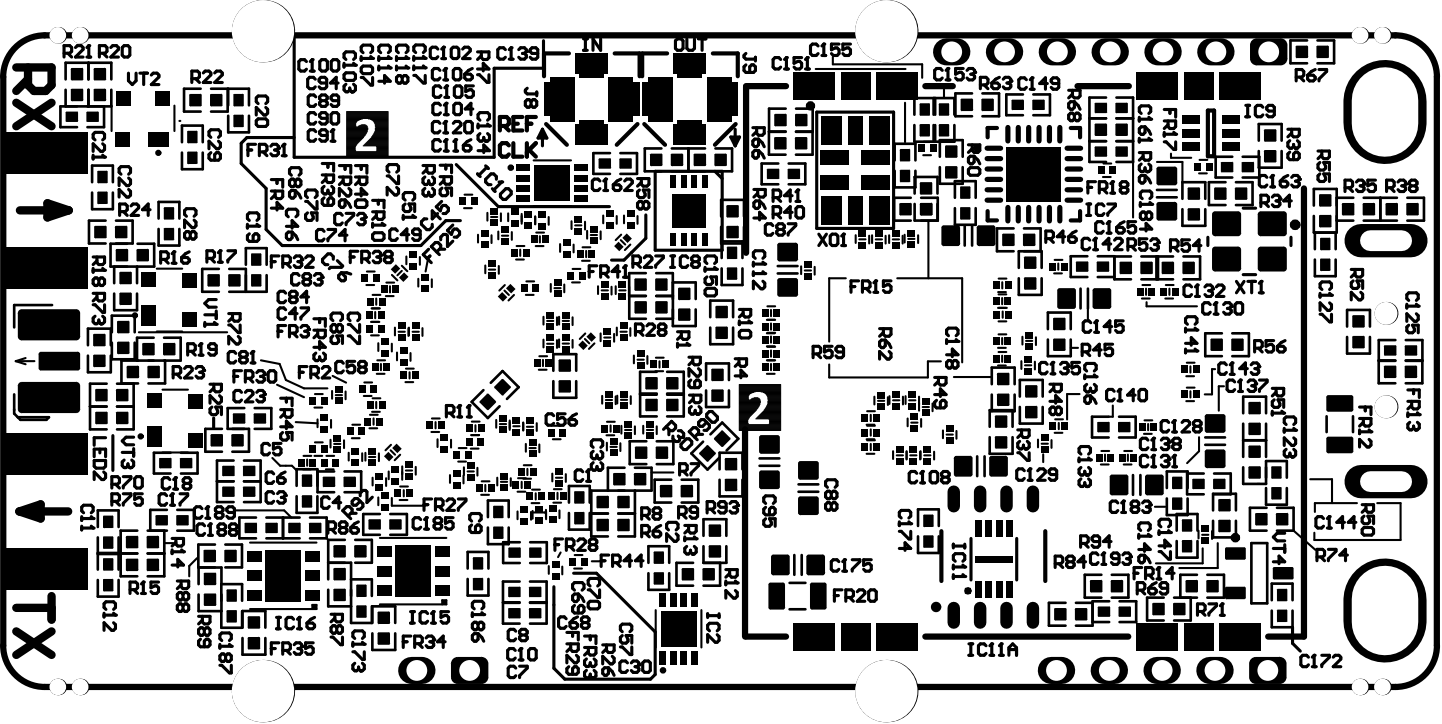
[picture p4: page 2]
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

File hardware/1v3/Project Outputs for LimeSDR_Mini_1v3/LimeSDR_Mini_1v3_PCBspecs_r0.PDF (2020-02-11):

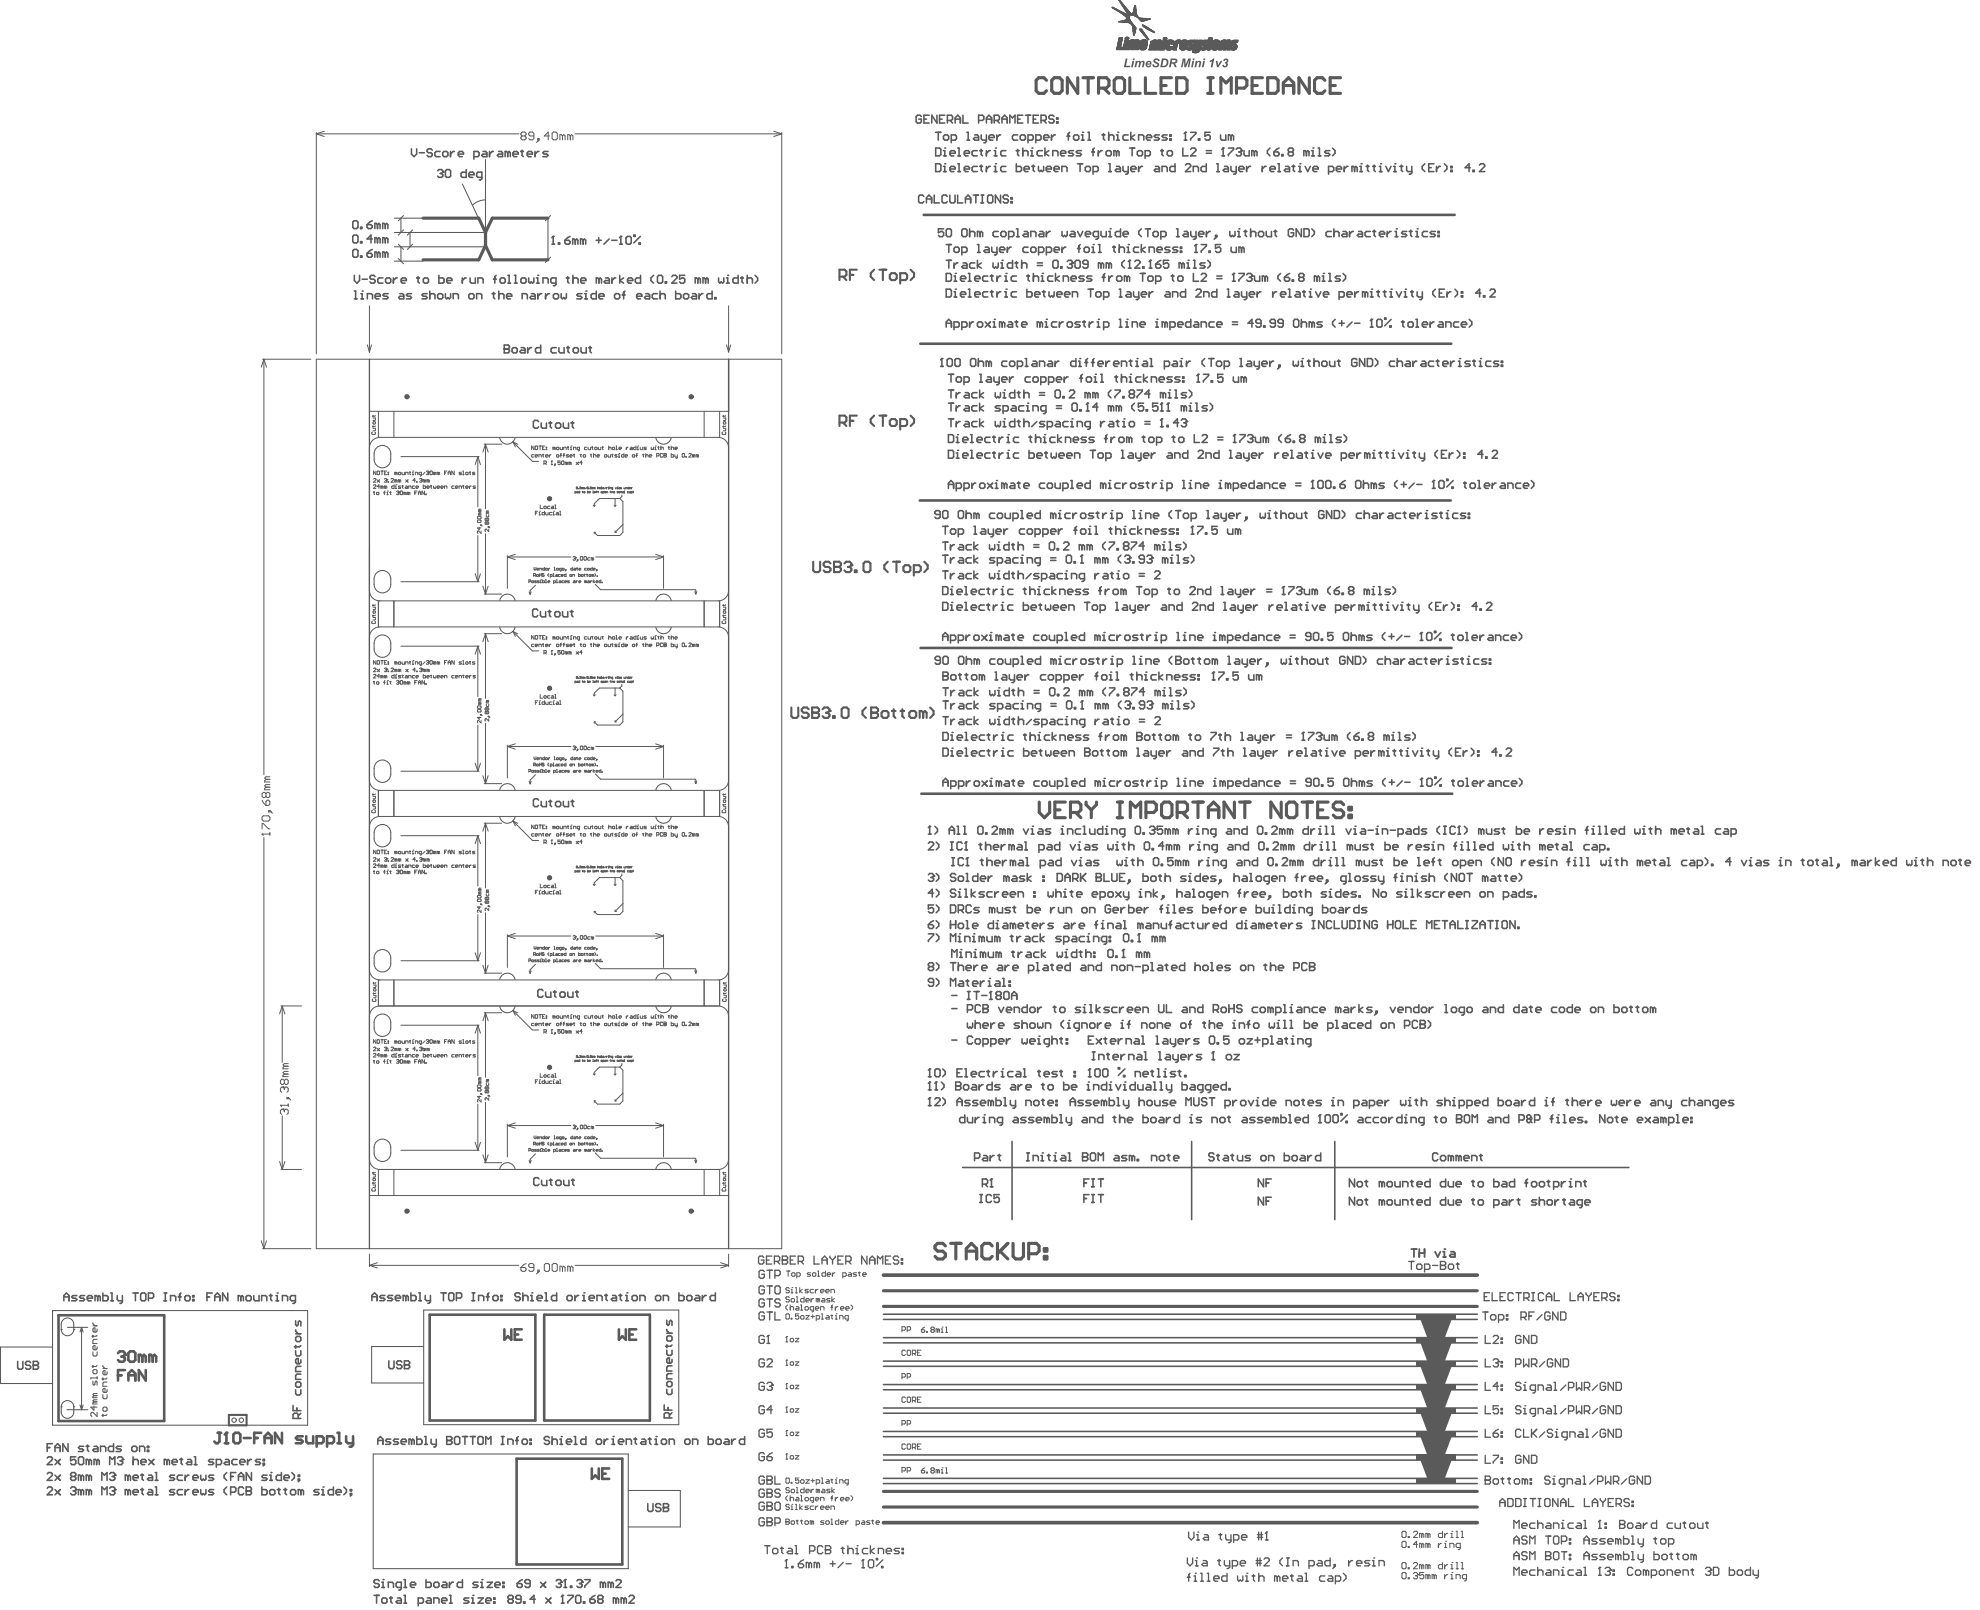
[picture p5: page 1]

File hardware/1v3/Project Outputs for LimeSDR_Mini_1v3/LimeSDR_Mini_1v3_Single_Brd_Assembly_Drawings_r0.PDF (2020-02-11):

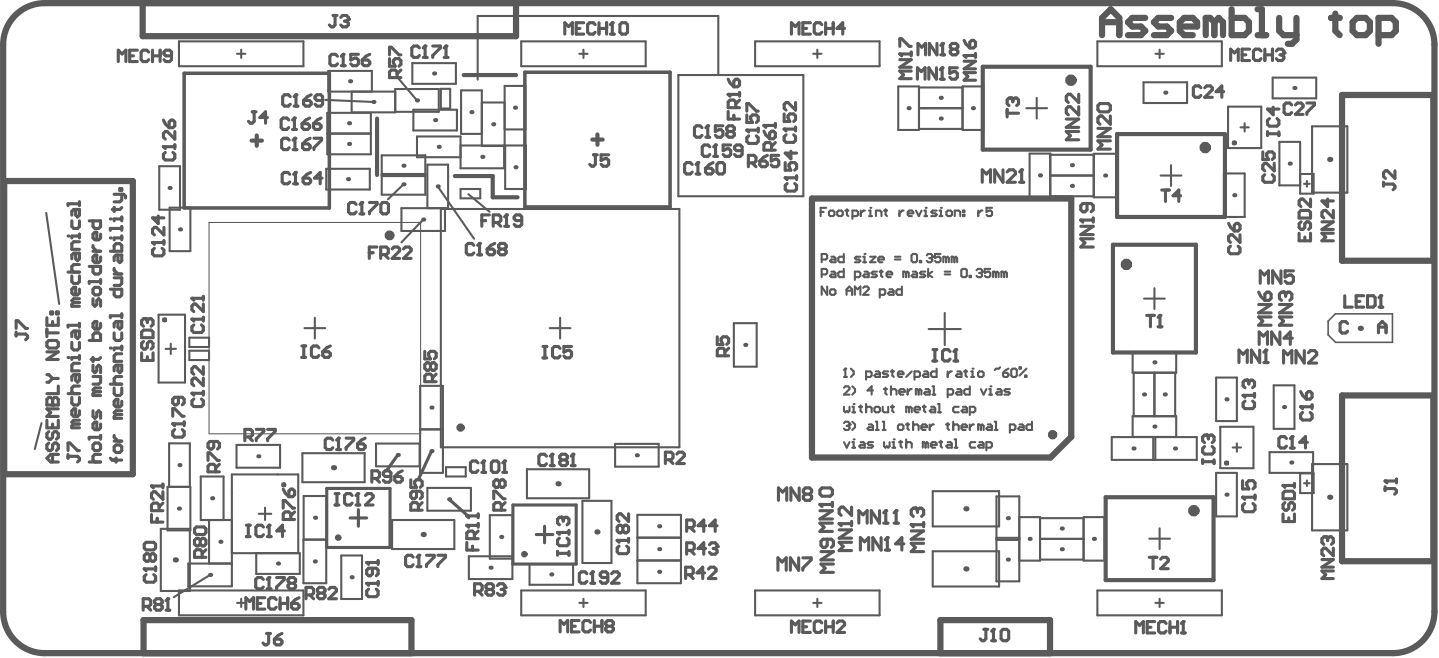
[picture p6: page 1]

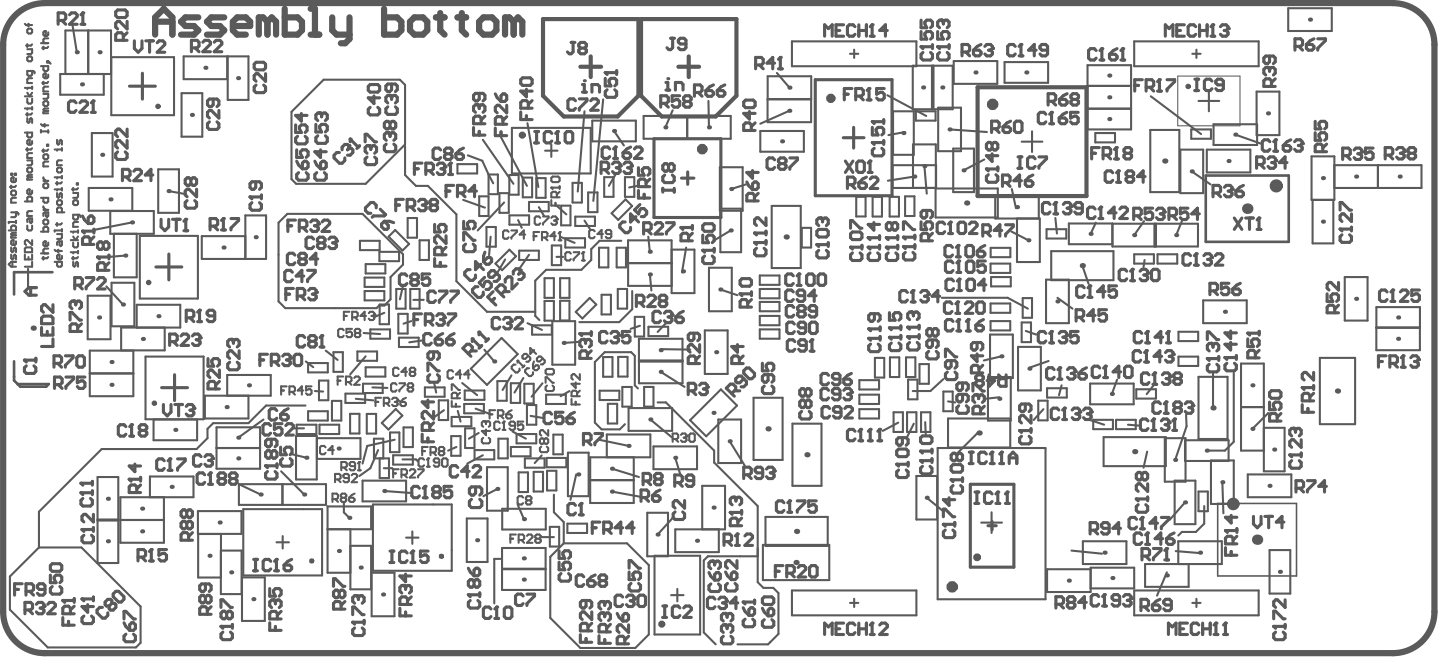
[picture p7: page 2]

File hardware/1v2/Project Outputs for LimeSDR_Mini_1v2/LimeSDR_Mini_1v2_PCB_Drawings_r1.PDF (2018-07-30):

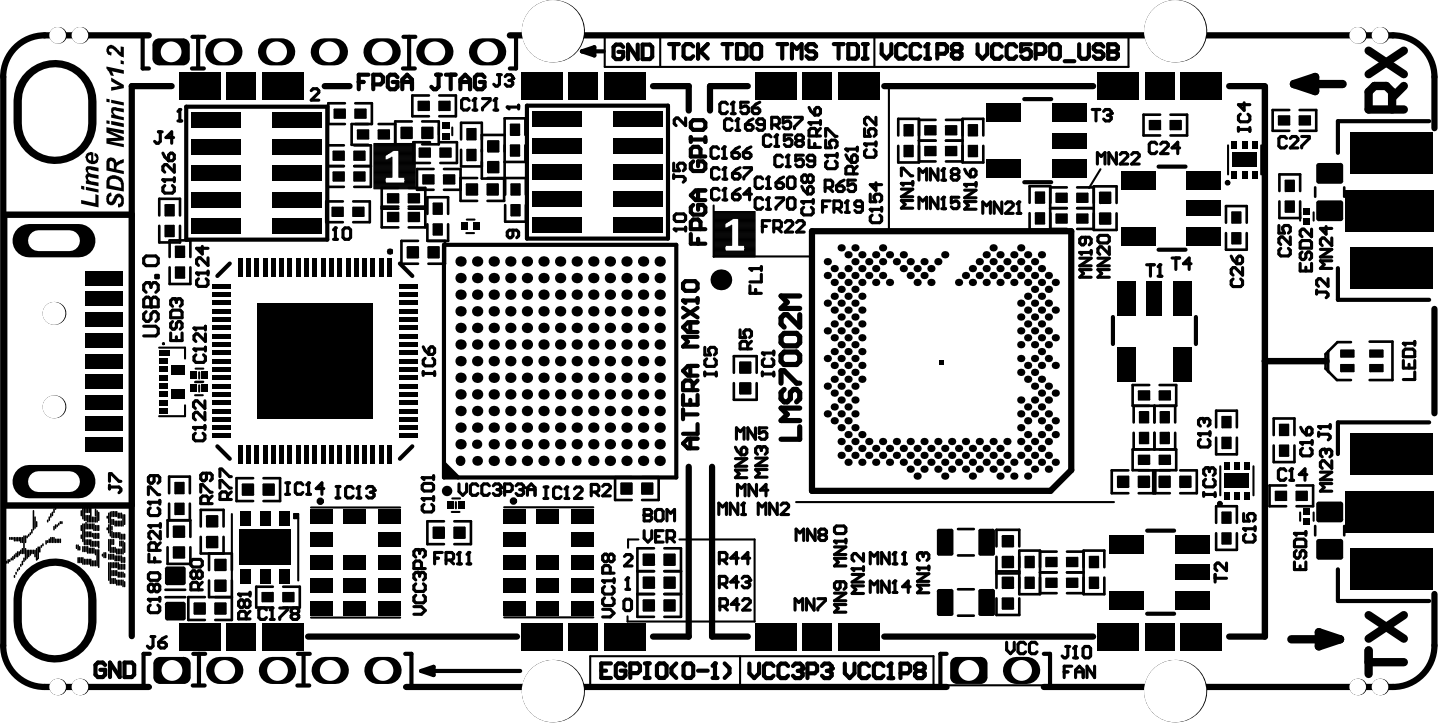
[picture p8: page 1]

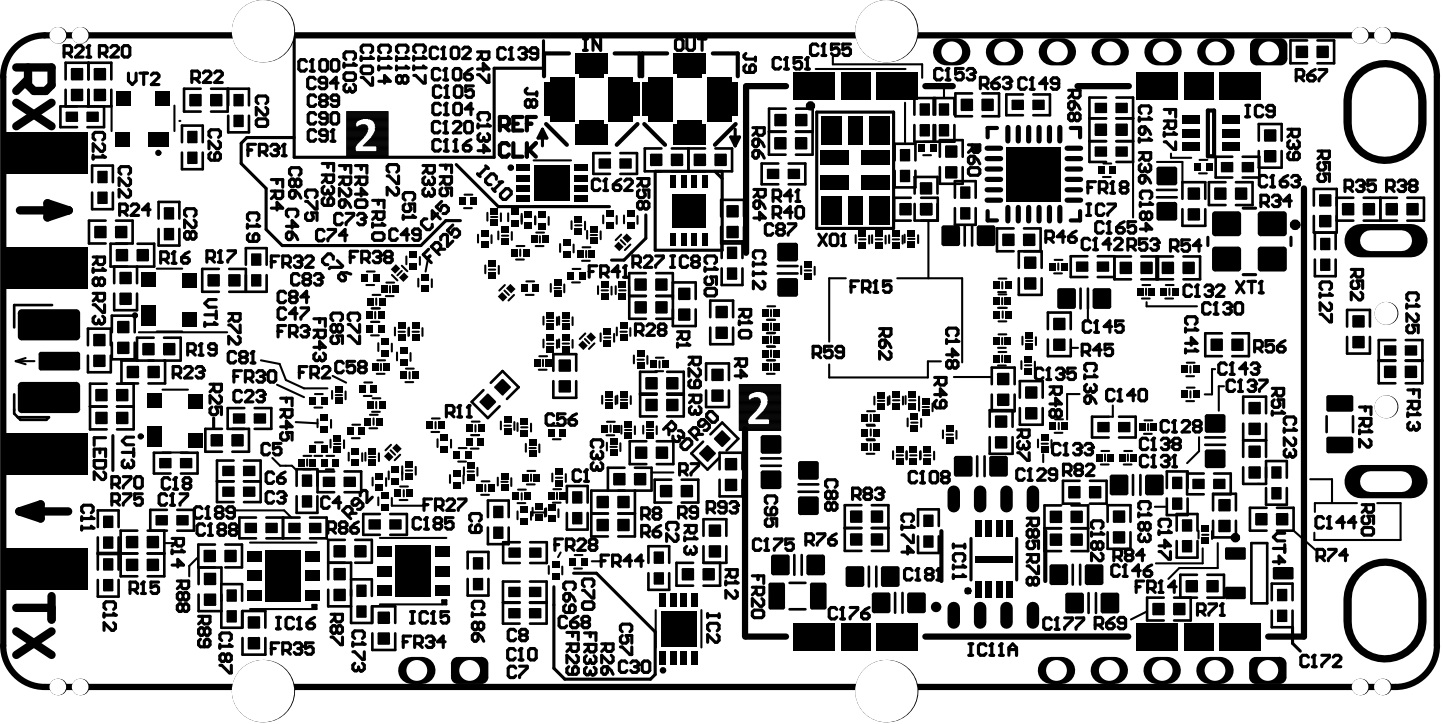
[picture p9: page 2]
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

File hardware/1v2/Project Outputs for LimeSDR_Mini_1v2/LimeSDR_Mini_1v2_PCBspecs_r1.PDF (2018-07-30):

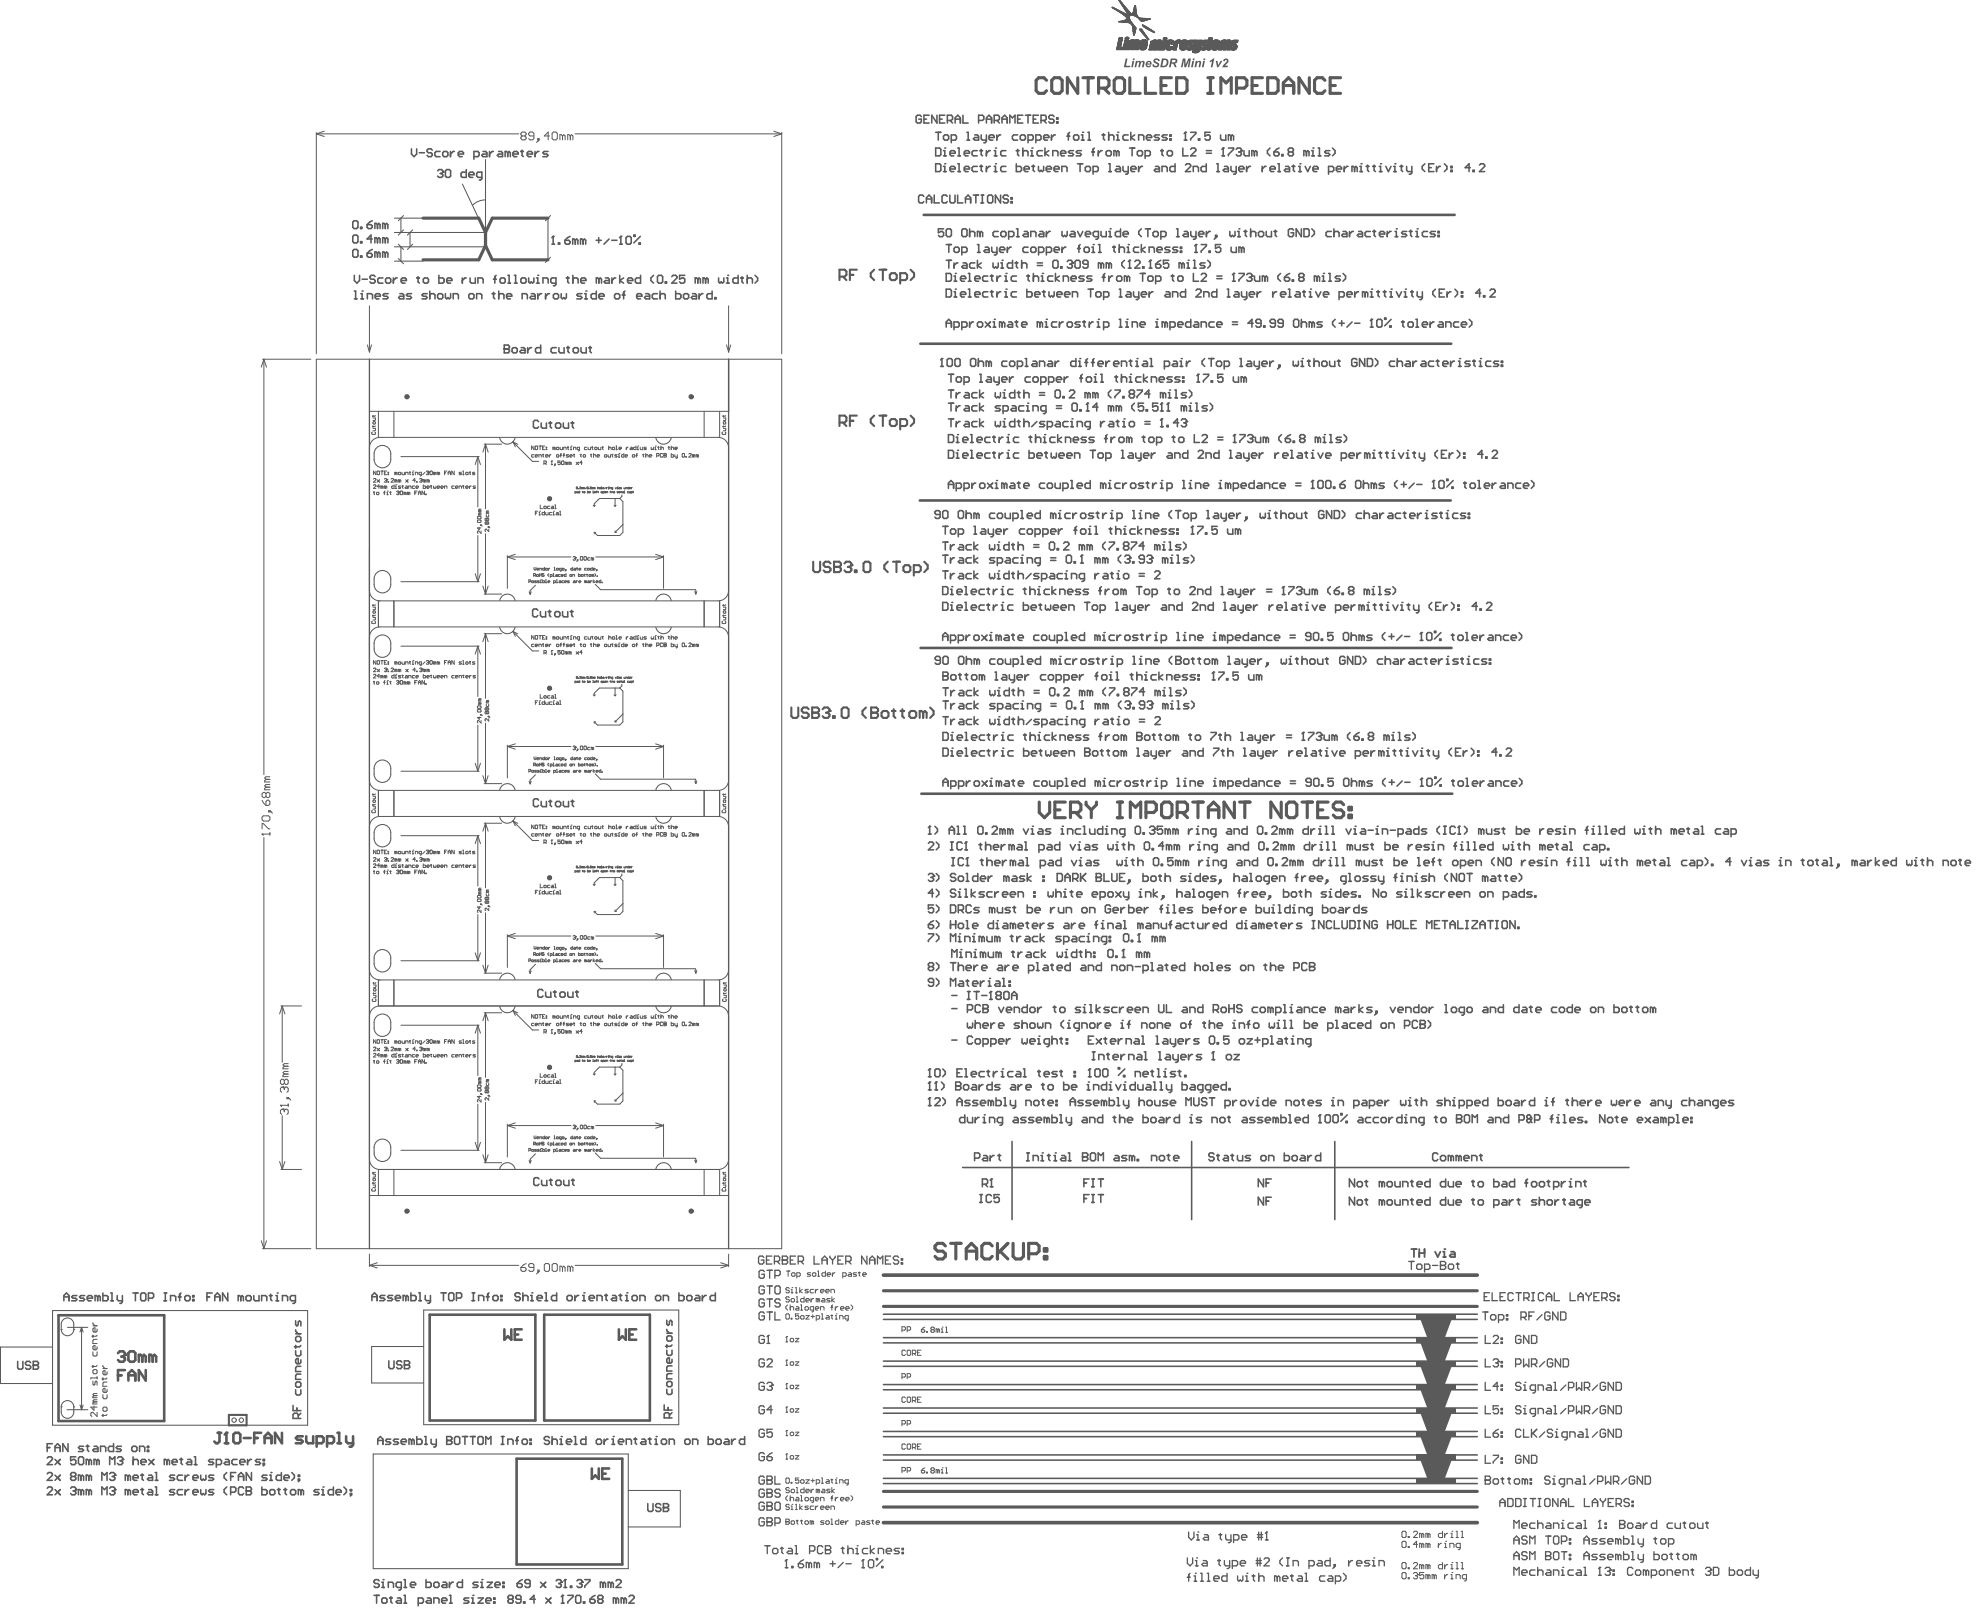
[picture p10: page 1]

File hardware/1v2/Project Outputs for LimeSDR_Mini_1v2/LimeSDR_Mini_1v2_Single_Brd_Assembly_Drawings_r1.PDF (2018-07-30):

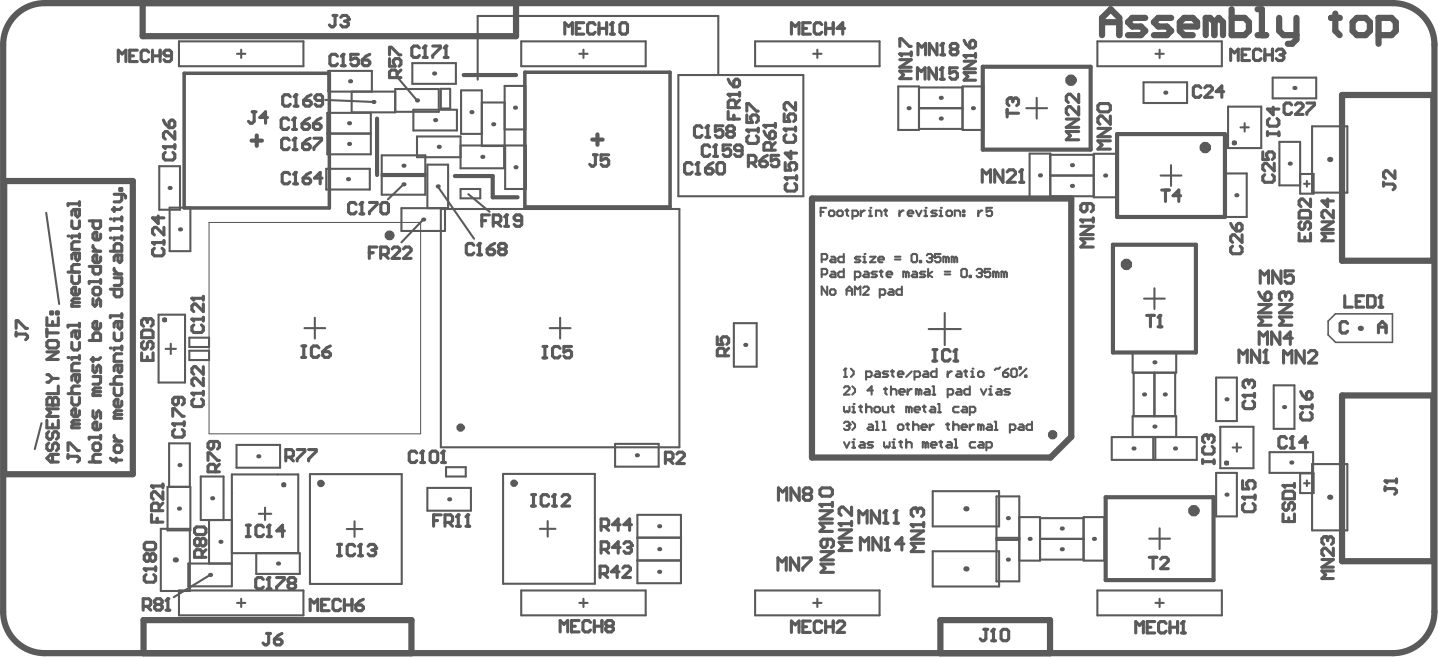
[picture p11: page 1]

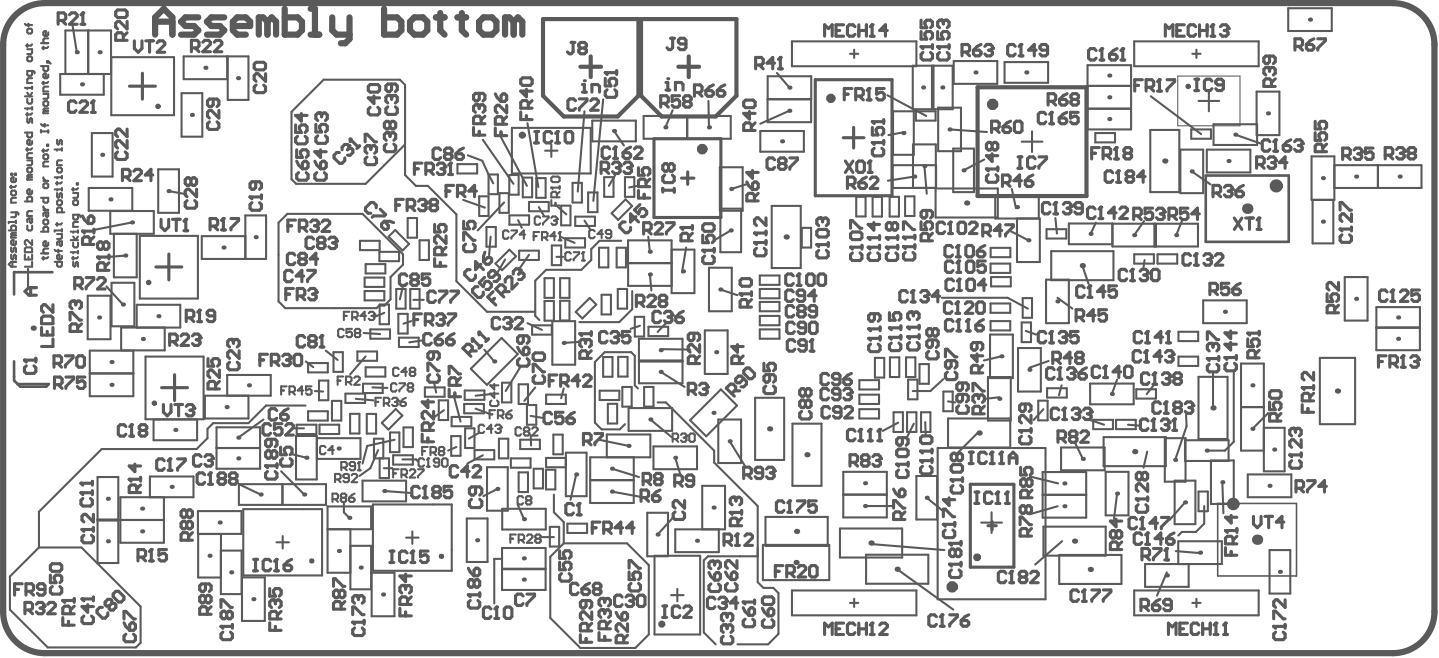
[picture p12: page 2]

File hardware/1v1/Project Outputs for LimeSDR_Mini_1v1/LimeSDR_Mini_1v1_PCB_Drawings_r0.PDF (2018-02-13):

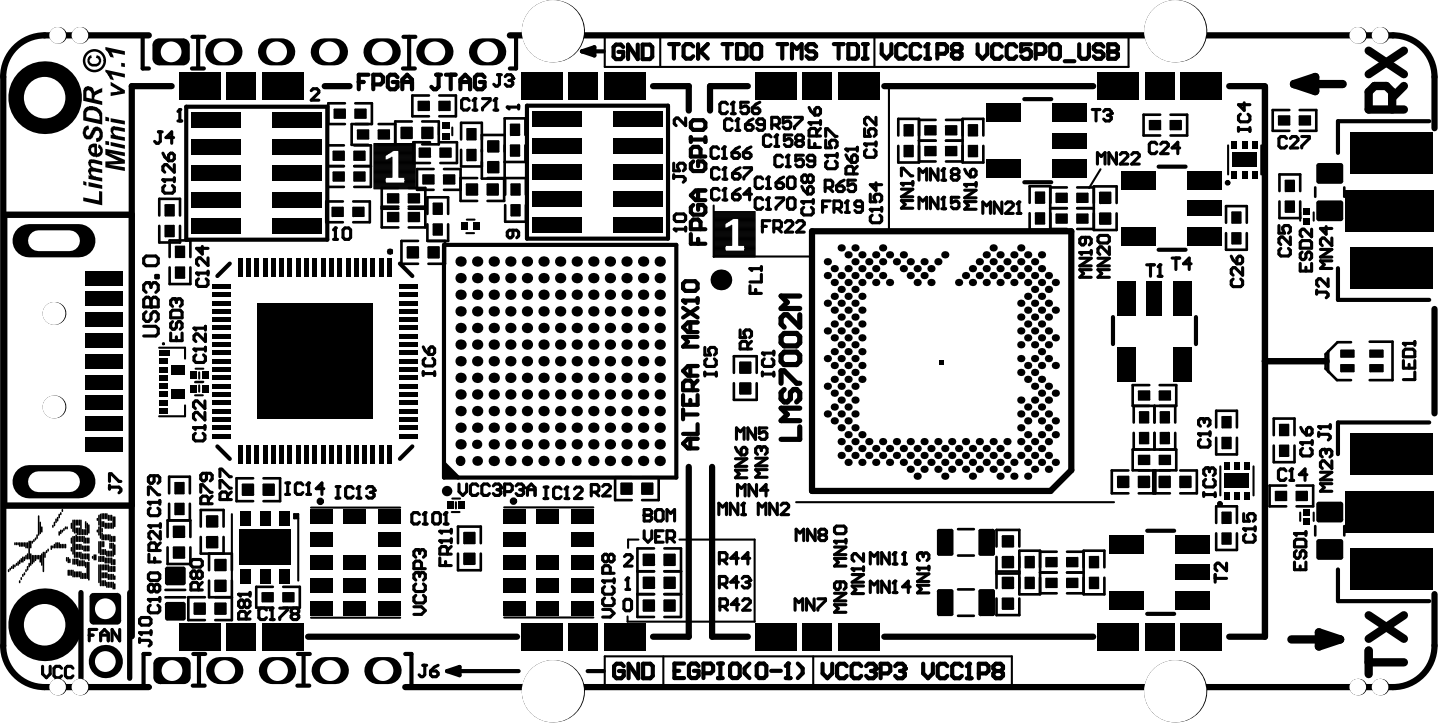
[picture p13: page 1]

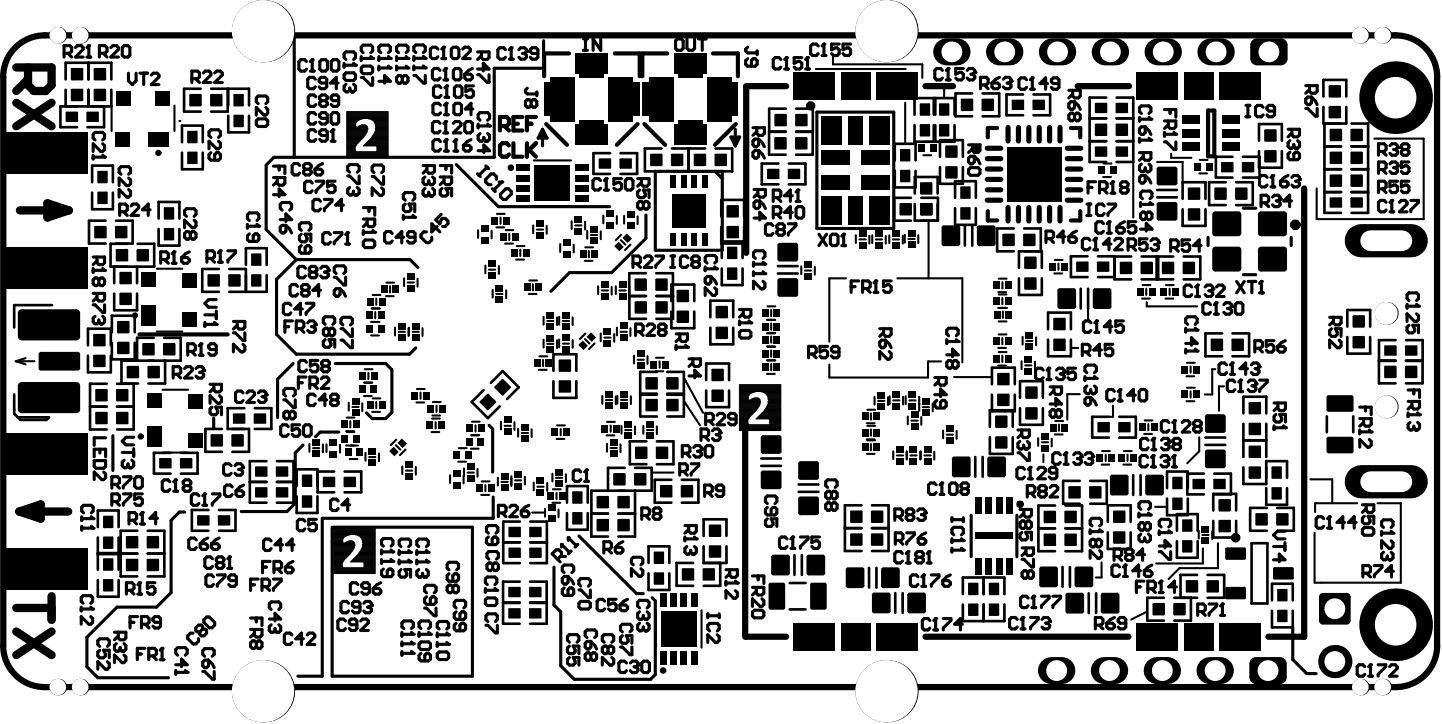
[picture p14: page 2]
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




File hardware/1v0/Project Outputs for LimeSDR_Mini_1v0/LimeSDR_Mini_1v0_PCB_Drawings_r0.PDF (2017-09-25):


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




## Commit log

2017-09-25 Initial Commit.
    [01_BlockDiagram.SchDoc, 02_PowerDiagram.SchDoc, 03_ClockDiagram.SchDoc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]
2017-09-25 Re-organised, added photo and updated README
    [01_BlockDiagram.SchDoc, 02_PowerDiagram.SchDoc, 03_ClockDiagram.SchDoc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]
2018-02-13 1v1 PCB project added.
    [01_BlockDiagram.SchDoc, 02_PowerDiagram.SchDoc, 03_ClockDiagram.SchDoc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]
2018-07-30 1v2 PCB design files added.
    [01_BlockDiagram.SchDoc, 02_PowerDiagram.SchDoc, 03_ClockDiagram.SchDoc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]
2020-02-11 Hardware version v1.3 added.
    [01_BlockDiagram.SchDoc, 02_PowerDiagram.SchDoc, 03_ClockDiagram.SchDoc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]
